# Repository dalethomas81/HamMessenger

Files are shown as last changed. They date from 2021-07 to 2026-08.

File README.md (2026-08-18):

> **⚠️ This repository is archived and no longer maintained.**  
> The code is left available for reference. No further updates, issues, or pull requests will be accepted.
> Please see [Meshtastic](https://meshtastic.org) or [Meshcore](https://meshcore.io) as superior alternatives. 

# HamMessenger # 
  
  

Hands on article about HamMessenger in IEEE Spectrum magazine [here](https://spectrum.ieee.org/ham-radio-text-hacking)  
Arduino blog post on HamMessenger [here](https://blog.arduino.cc/2021/07/27/send-text-messages-over-ham-radio-with-the-hammessenger/?queryID=undefined)  
Hackaday blog post on HamMessenger [here](https://hackaday.com/blog/?s=hammessenger)  

HamMessenger is a portable, battery powered device that runs on a microcontroller and interfaces with an inexpensive ham radio to send and receive text messages and provide position updates using the [APRS](http://www.aprs.org/doc/APRS101.PDF) protocol. Messages and position updates sent via HamMessenger can be viewed on sites such as [aprs.fi](https://aprs.fi). HamMessenger messages are NOT encrypted!  

HamMessenger is intended to be used by licensed ham radio operators. For more information you can check out the [ARRL](http://www.arrl.org/what-is-ham-radio) website.  

The goal of the HamMessenger project is to create a device that uses ham radio as a medium for sending and receiving text messages. HamMessenger exists also to promote amateur radio, electronics, and programming. The project is currently in a beta prototyping stage but does function quite well. 

At the core of the the project is the [MicroAPRS](https://github.com/markqvist/MicroAPRS) modem created by [markqvist](https://github.com/markqvist). The primary controller is an Arduino Mega 2560 with the MicroAPRS Modem running on an Arduino Pro Mini. HamMessenger includes GPS functionality supplied by a Neo-6M GPS radio. For peripherals, an M5Stack CardKB keyboard is used for input and an SSD1106 Oled display for output.  

I will add some videos and pictures of the device in action asap. Please feel free to contribute to the project. I am very busy outside of this project so any help is greatly appreciated :)  

<table>
  <tr>
    <td align="center">
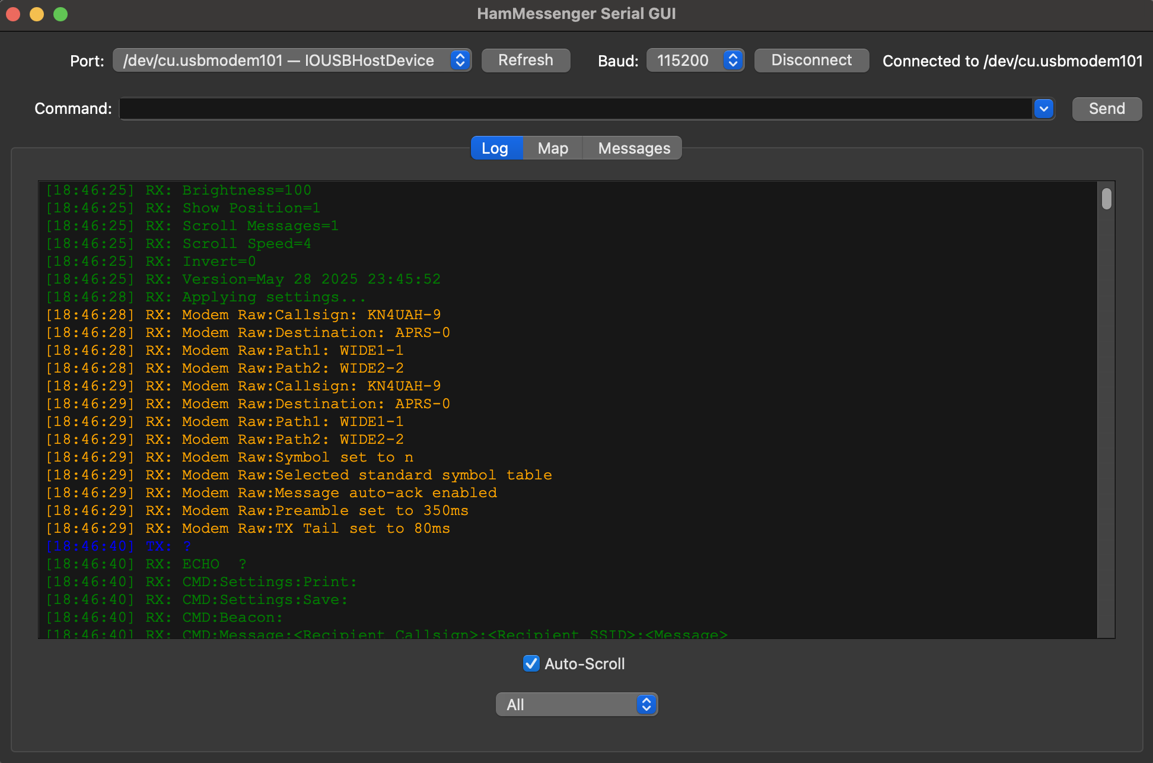
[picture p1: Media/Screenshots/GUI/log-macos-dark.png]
      <br/>
      <sub>MacOS Log Screen</sub>
    </td>
    <td align="center">
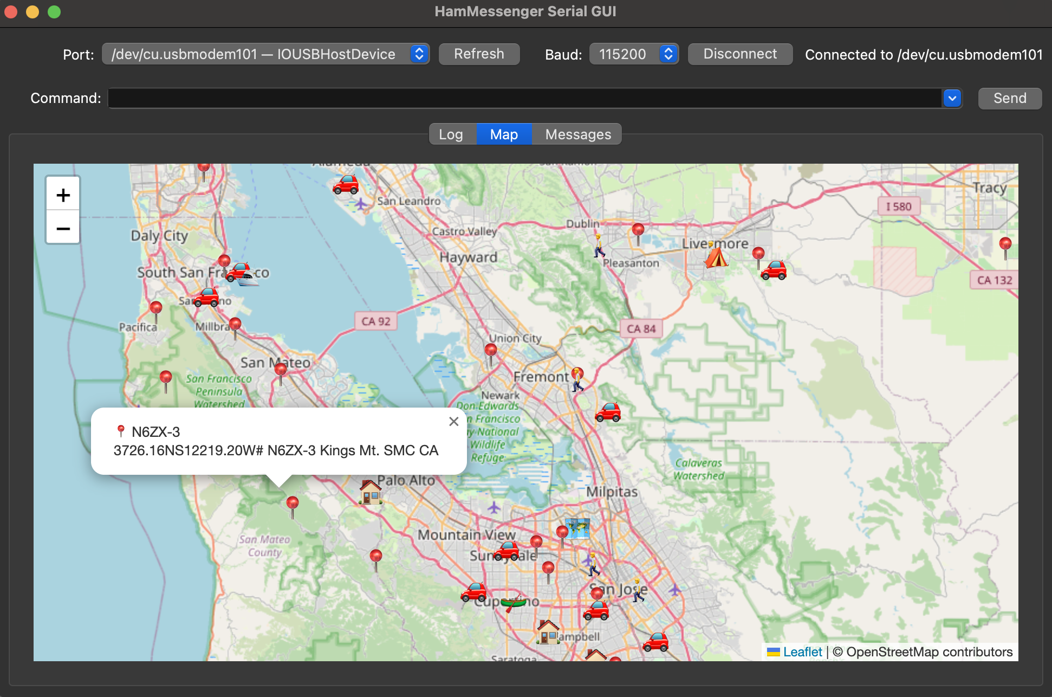
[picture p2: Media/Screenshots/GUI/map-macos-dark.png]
      <br/>
      <sub>MacOS Map Screen</sub>
    </td>
  </tr>
</table>

<table>
  <tr>
    <td align="center">
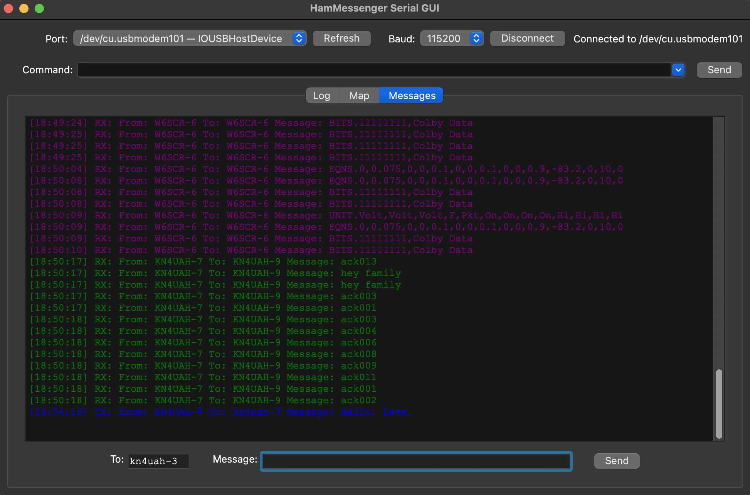
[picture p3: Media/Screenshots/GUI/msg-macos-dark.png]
      <br/>
      <sub>MacOS Message Screen</sub>
    </td>
    <td align="center">
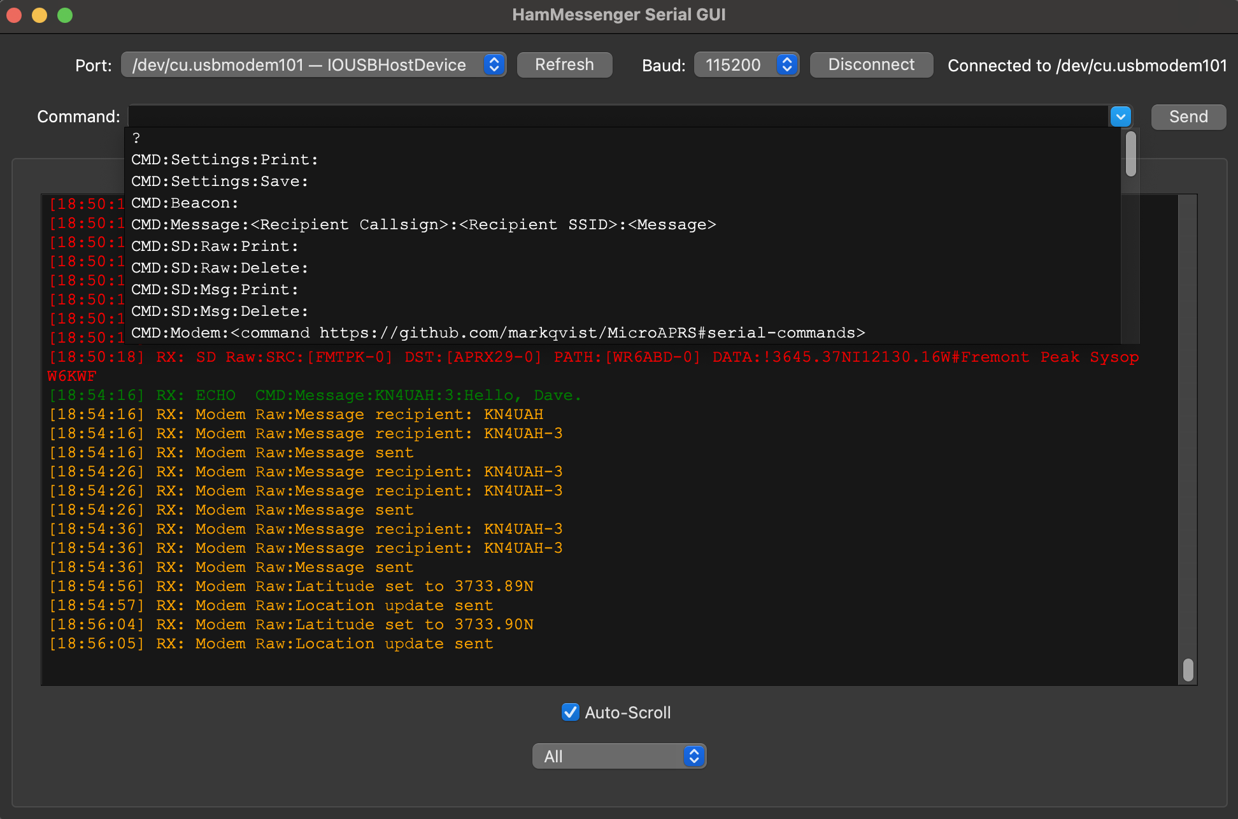
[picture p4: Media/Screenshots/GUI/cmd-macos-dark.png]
      <br/>
      <sub>MacOS Commands Example</sub>
    </td>
  </tr>
</table>

<table>
  <tr>
    <td align="center">
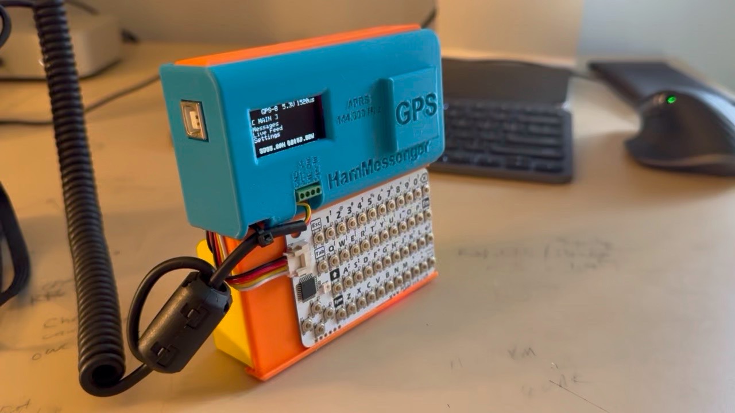
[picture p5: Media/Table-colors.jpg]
      <br/>
      <sub>Full Enclosure</sub>
    </td>
    <td align="center">
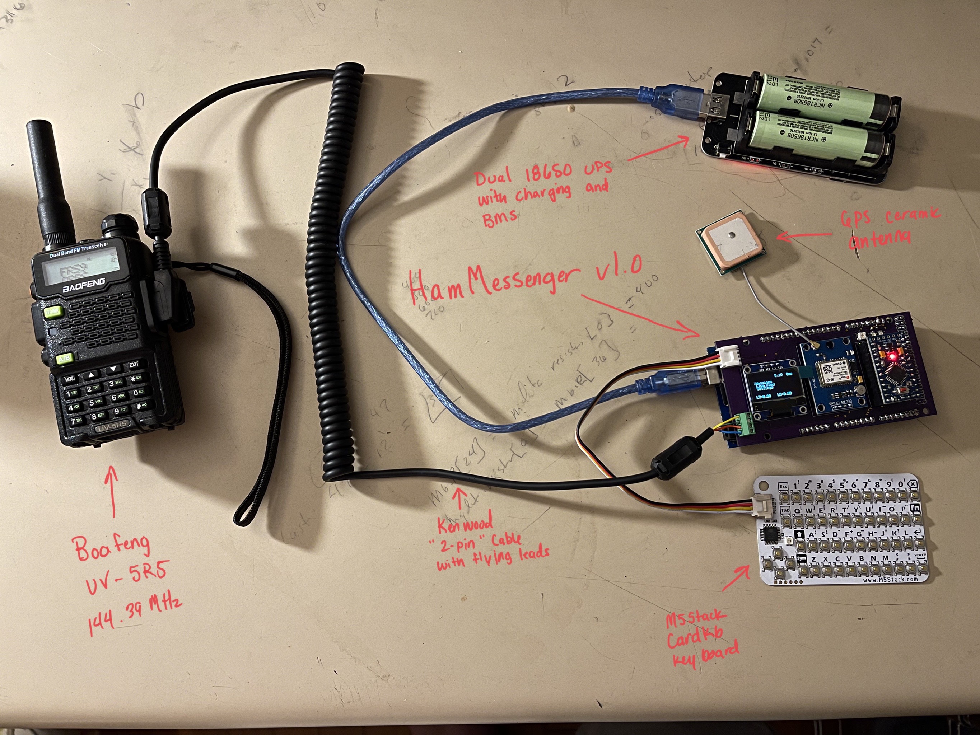
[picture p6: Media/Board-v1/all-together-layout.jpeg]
      <br/>
      <sub>Component Layout</sub>
    </td>
    <td align="center">
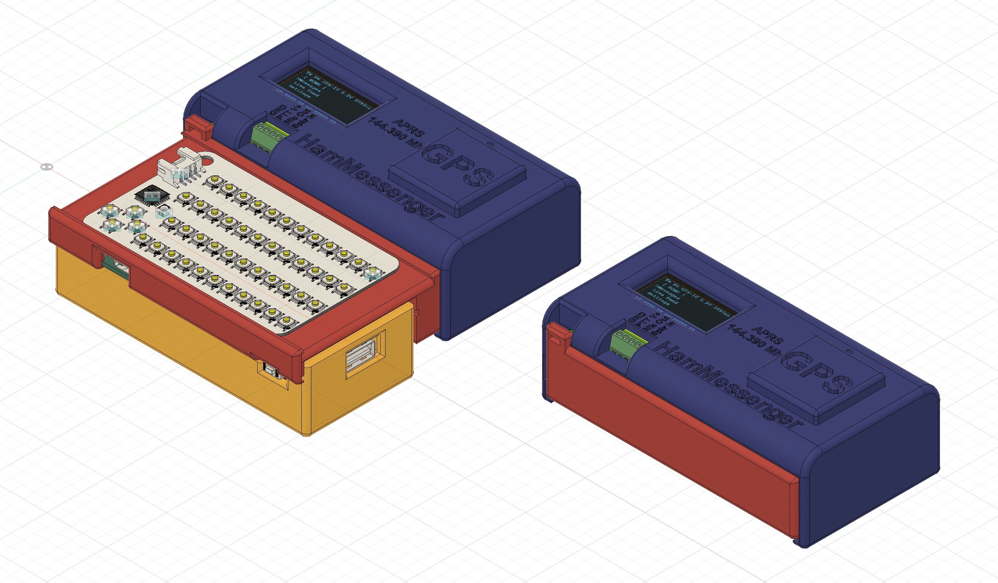
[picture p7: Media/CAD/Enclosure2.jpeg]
      <br/>
      <sub>CAD Isometric</sub>
    </td>
  </tr>
</table>

## Operation ##

Full instructions on how to operate HamMessenger will go here. For now, just a couple notes :)  

HamMessenger will beacon your location and comment according to the 'Beacon' settings in `APRS` Settings.  
- `Beacon Distance` is the distance in miles that will trigger a beacon.  
- `Beacon Idle Time` is the time in milliseconds that the station must be in the same location after having moved from the last beacon location before a beacon will be sent.
- `Position Tolerance` under `GPS` settings is the +/- value that will trigger a location update.  

To send a direct message to a station, select `Messages` on the `HOME` screen and press `Enter` on the keyboard. This will open the `NEW MESSAGE` screen.  
- `Message Text` is the message that will be sent.  
- `Recipient Callsign` is the callsign of the station that will recieve the message. Example 'NOCALL-ID'  
- `Recipient SSID` is the ID of the station that will recieve the message. Example 'NOCALL-ID'  

Screen navigation information can be found [here](https://github.com/dalethomas81/HamMessenger/blob/master/Documentation/Operating%20Instructions/Screen%20Navigation.md).  

Radio setup instructions can be found [here](https://github.com/dalethomas81/HamMessenger/blob/master/Documentation/Operating%20Instructions/Radio%20Setup.md).

Serial interface information can be found [here](https://github.com/dalethomas81/HamMessenger/blob/master/Documentation/Operating%20Instructions/Serial%20Interface.md).

## TODO ##

hardware:
- improve enclosure design  

software:
- add ability to program the radio once connected for 'plug-n-play' experience (is this possible?)  
- add feature to be selective about message acknowledgments. currently any acknowlegment (from a second conversation) will reset the messaging sequencer.  

## Libraries ##

Here are links to the non-standard libraries that I am using for this project. All other libraries are standard and can be installed using the library manager built into the Arduino IDE.  
- https://github.com/wonho-maker/Adafruit_SH1106  
- https://github.com/mikalhart/TinyGPSPlus  
- https://github.com/adafruit/Adafruit-GFX-Library  
- https://github.com/Xander-Electronics/Base64  

## Compilation ##

The easiest way to compile HamMessenger is to use the Ardunio IDE. After all libraries are installed you can use the Verify button to compile or the Upload button to compile and write the binary to the main controller M1. 

The Arduino source code for HamMessenger can be found [here](/Source/HamMessenger).

The modem controller does not need to be compiled as the binary files are already made available [here](https://github.com/markqvist/MicroAPRS/tree/master/precompiled).  

You can use AVRDude to write the binary to the modem controller. Instructions on how to do that will be coming soon. In the meantime, if you already know how to install and use AVRDude then feel free to make use of the [batch](/Source/MicroAPRS%20Firmware%20Installer) file I created and an [FTDI](https://www.amazon.com/gp/product/B00DDF8TV6/ref=ox_sc_act_title_4?smid=A2SXV8GJXX3WPH&psc=1) serial cable to write to the modem.

## Parts ##

Find BOM information on parts [here](/Documentation/Parts/BOMs)  
Find Drawing information on parts [here](/Documentation/Parts/Drawings)  
Find Vendor information on parts [here](/Documentation/Parts/Vendors)  

### Part Specs ###

Arduino:  
https://gallery.autodesk.com/fusion360/projects/arduino-mega-2560-r3  

Keyboard:  
https://github.com/m5stack/M5-ProductExampleCodes/tree/master/Unit/CARDKB  

OLED Display:    
https://grabcad.com/library/0-96-oled-display-4-pin-1  
https://grabcad.com/library/ecran-oled-1-3-1

Modem:  
https://github.com/markqvist/MicroAPRS  
https://github.com/markqvist/MicroAPRS/blob/master/precompiled/microaprs-5v-ss-latest.hex  
https://github.com/markqvist/MicroAPRS/blob/master/documentation/Hardware%20Schematic.pdf  
https://unsigned.io/shop  
https://unsigned.io/product/micromodem-r23b  

GPS:    
https://grabcad.com/library/gps-module-ublox_neo6mv2-1  
https://grabcad.com/library/ecran-oled-1-3-1  

Grove Connector:  
https://grabcad.com/library/grove-connectors-stand-and-flat-male-plugs-1/details?folder_id=2820551  

Battery:  
Panasonic 18650 - don't have a link but you can get them on eBay or Amazon  

## Updates ##

### 31-MAY-2025: Major updates!

I have made some major updates to the board (RF filtering for the PTT), to the enclosure, and to the firmware (many improvements to the display including a dedicated "New Message" display). Additionally, I have created a companion GUI app that you can use to connect HamMessenger to your PC.  

I have ordered parts to begin building 3 new HamMessengers and will begin building them next week. The purpose is to create some instructional videos and documentation to help support anyone that wants to build one themselves. I also plan to donate these builds to my local Ham club.  

There is now a new [Build Instructions](/Documentation/Build%20Instructions/) folder that I will use to put the tutorial references and documentation.  

### 08-SEP-2021: Troubleshooting freezing

There is an issue where during transmit the unit will freeze or restart. I did some experimenting and found out that its the cable that connects to the radio. It is not shielded at all. I thought the small ferrites would be enough to combat this but obviously not. I did some experimenting and found that if I use larger ferrites and wrap them once that the issue goes away. [Here](/Media/Install/large-ferrites.jpeg/) is a picture of the installation. I will now look at sourcing a shielded cable for this application.

### 05-SEP-2021: First version of the enclosure

So I started learning 3D modeling so that I can create an enclosure for HamMessenger. Its been a bit of a learning curve but I'm getting the hang of it. I decided that for the first iteration I would go with an open unibody frame. I chose this style for the first version because it is easy and I'd like to have something working while I learn more about 3D modeling.

You can find the Fusion 360 archive file and the stl [here](/Documentation/CAD/Fusion-360/). It needs to be printed on its side like [this](/Media/Unibody-Frame-v1/cura.png/) to minimize the amount of support needed during printing. I used 0.2mm layers with 20% infill as well as 5% support infill. The print took about 6.5 hours.

A few pics:  
[Front](/Media/Unibody-Frame-v1/front.jpeg/)  
[Side](/Media/Unibody-Frame-v1/side.jpeg/)  
[Back](/Media/Unibody-Frame-v1/back.jpeg/)  

### 14-AUG-2021: Rev v1.1 has arrived and it works!

Ok, great news. Revision v1.1 of the HamMessenger board came in from PCBWay and they are great. I built 2 units and was able to encode and decode messages well. I will add some more information later but [here](/Media/Board-v1.1/) is a few pictures for now.

### 24-JUL-2021: Rev v1.1 is being fabbed!!

I was able to work through all of the issues with the first version. I placed an order with jlcpcb this time (osh park was great but too expensive). I ordered 20 boards this time and if they work well I will give some away.  

I'll update later with how I resolved the issues. For now, going to have a beer :)

### 22-JUL-2021: Put together some information on the board for your review.

[Here](/Media/Board-v1/analysis.md) is an in-depth analysis of the problems with version 1.0 of the board. Also, does any body know how to add correct shielding for the board? I am having issues with the Arduino locking up on transmit sometimes.

### 21-JUL-2021: Made revisons to the board resolving and improving the following:

1. add ground to SD card
2. add OE connection to line leveler
3. reverse I2C connections
4. change GPS I/O to correct serial
5. purchase correct GPS (added new link in BOM)
6. move SD card away from USB.
7. move keyboard grove to bottom of board and out of way
8. move 4 pin terminal for cable such that it is out of the way of larger OLED
9. ground plane improvements.  

still left to do:

1. board does not receive (soldering issues?)  
2. board some times locks up during transmit (ground plane issues?)  

### 20-JUL-2021: Bad news on the boards :( Lots of problems. I will begin immediately working on a revision. Here is a list of the issues:

1. SD Card missing ground
2. Line leveler missing OE connection.
3. I2C connections are reversed.
4. GPS is pointing to wrong serial ports (can fix with code but might as well make it right).
5. GPS pins do not match board. (worked around this by shifting pins)
6. Cannot not receive (don't know why at this point).
7. SD card hits Arduino USB. Will move it and the Grove connector to make room.
8. Arduino periodically locks up. Seemingly due to RF? Had this issue with prototype board but fixed it with ferrites.

### 18-JUL-2021: The printed circuit boards from OSH will be arriving tomorrow! I have added all of the parts needed to build HamMessenger [here](/Documentation/Parts/BOMs).

04-JUL-2021: Version 1 of the pcb for HamMessenger has be sent for fabrication. The estimated delivery date is the 22nd of July. In the meantime I will be ordering the components to populate the board. As I do that I will make sure to get the links for the components and add them to the BOM in the Eagle folder.

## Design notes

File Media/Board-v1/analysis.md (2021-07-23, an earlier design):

# Analysis of HamMessenger v1.0 #  

After receiving the board and soldering the SMD components, it became very apparent that a new revision would be in order. Here is what I found...  

# Form #

1. At first sight you can see that the board will not mate flush with the Arduino due to poor placement of the SD card mechanism and the Grove connector. I will be moving these as one of the first improvements.
2. Next, you can see that the modem (Arduino Pro Mini) has all of its supporting hardware mounted underneath it. This was done on purpose to save space but I think a better option would have been to place the components on the other side of the board. I may do that in a later revision. But, for now I have added female 2.54mm headers so that the Pro Mini can be removed for troubleshooting and repair.
3. The last major form issue is the display. It is just too small. The prototype version uses a non-standard 1.2" OLED that is controlled by a sh1106 instead of a ssd1306 (and consequently needs a modified library). I decided that I would give the standard 0.96" display a try since they are very common and use the out-of-the-box version of the Adafruit ssd1306 library. However, its just too damn small!
4. Bonus: while we're on the subject of form - you will notice how terrible of a job I did on the smd soldering. It was my first time but I think (hope) the next board will look better :)

# Function #

1. The first functional issue was with the SD card. This actually counts as 2 issues. One was that I missed a ground on my SD card mechanism. The other was that I missed feeding vcc to the OE pin of the line-level shifter. I repaired both of those with jumpers so that I could troubleshoot the rest of the board.
2. The next functional issue is that the OLED display and the keyboard would not work. I had gotten the SDA and SCL lines for I2C crossed. You'll see a picture below of the disgusting job I did of fixing that.
3. Next, you can see that I ordered the wrong GPS unit (correct one on the BOM now). Luckily, it worked out that the correct one has an extra pin (pps) and it just so happened that I could scoot this one over a pin and run a jumper for the power and get it to work. So technically, this isn't an issue with the board but I'm listing it here.
4. After I got the GPS installed and powered, I noticed that the coordinates were not being populated in the bottom of the display. This was because I routed the serial wires to the wrong serial ports of the Arduino. Doh. That was an easy change in the software to get this one working but I will make it right on the next version of the board.
5. Moving on to encoding and decoding messages - it doesn't encode messages as good as the prototypes and I haven't gotten it to *decode* a message at all yet. I'm going to remove the Arduino Pro Mini and try to reflow some of those components. Admittedly, I did not do a very good job soldering these.
6. Oh, and lastly - sometimes the Arduino will lock up on transmit. This was an issue that I saw with the prototype boards and thought it must be an issue with not having a ground plane or shielding. I "fixed" the issue by adding ferrite cores to the cable between HamMessenger and the radio. The problem went away but it is now present in this board even with the ferrite cores. If anyone knows a thing or 2 about how to shield this board from RF, I would love to hear from you.

# Pictures #

all-together-layout  

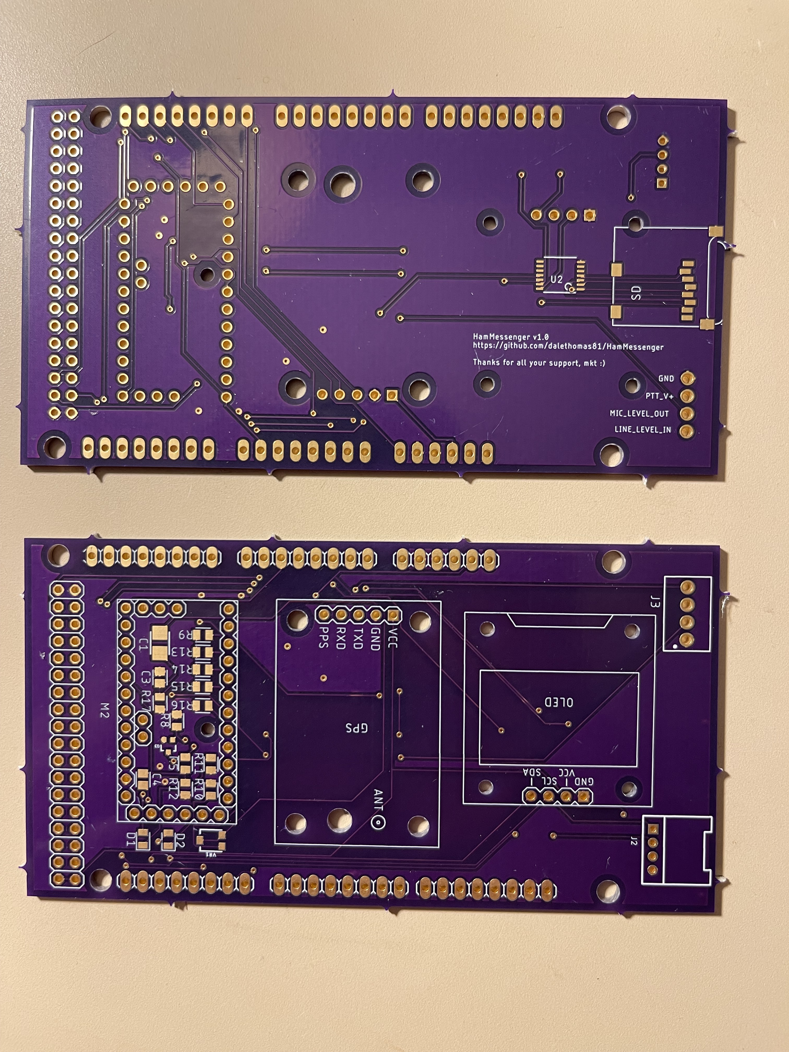
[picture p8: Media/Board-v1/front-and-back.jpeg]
front-and-back
  

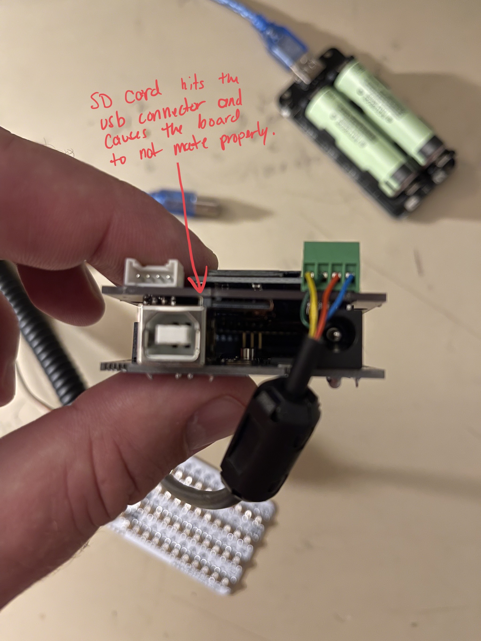
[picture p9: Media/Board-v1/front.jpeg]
front
  

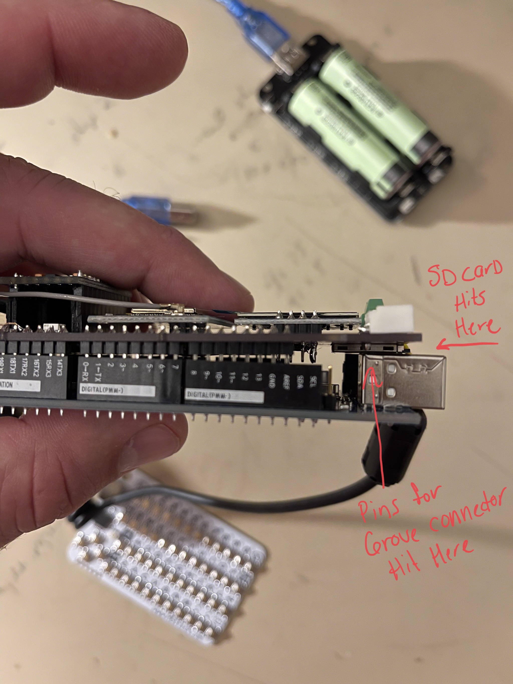
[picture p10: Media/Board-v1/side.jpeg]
side
  

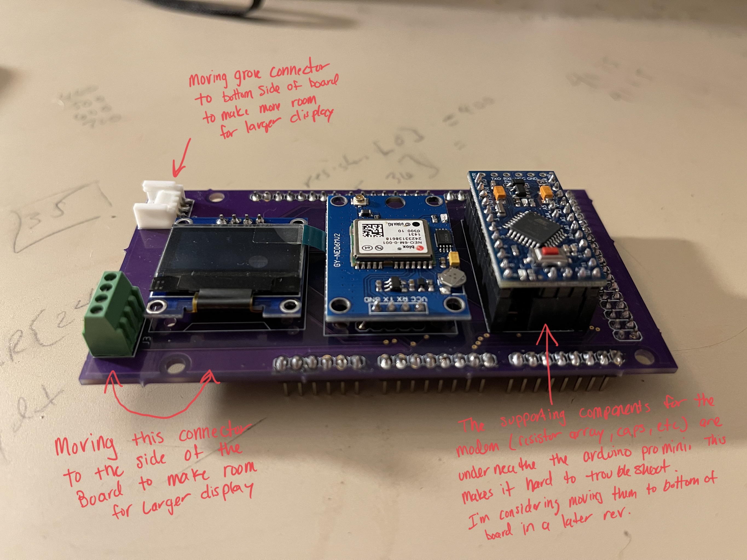
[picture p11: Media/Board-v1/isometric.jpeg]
isometric
  

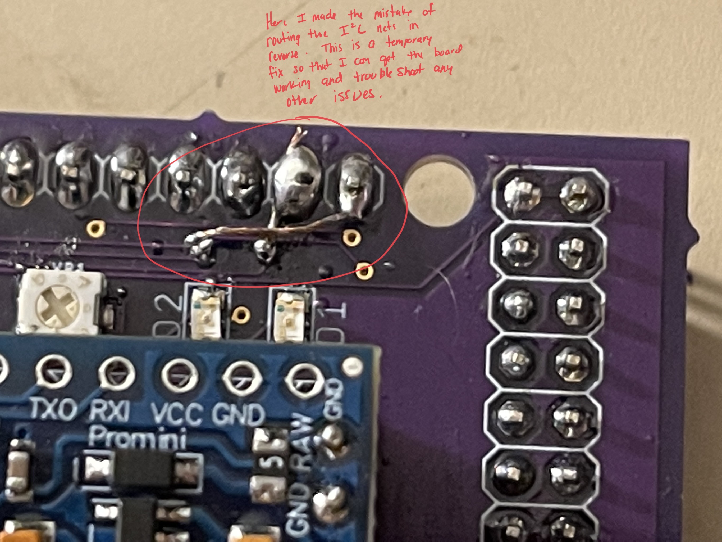
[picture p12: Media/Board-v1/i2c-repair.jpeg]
i2c-repair
  

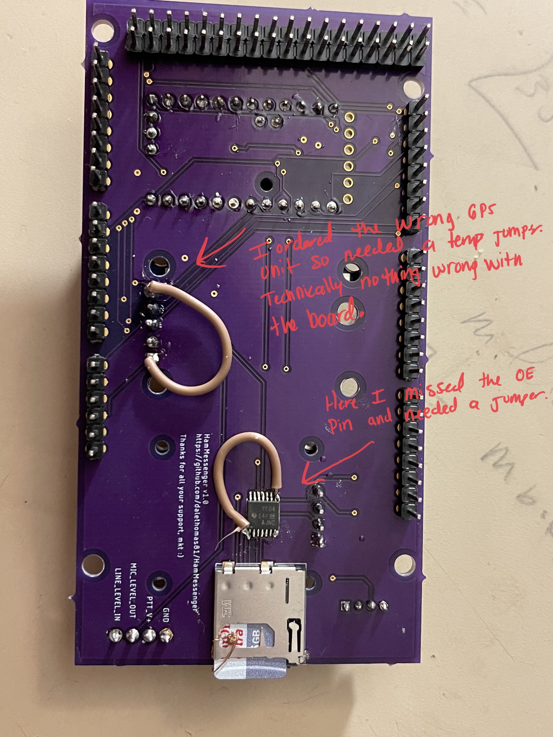
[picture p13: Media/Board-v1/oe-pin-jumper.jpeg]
oe-pin-jumper
  

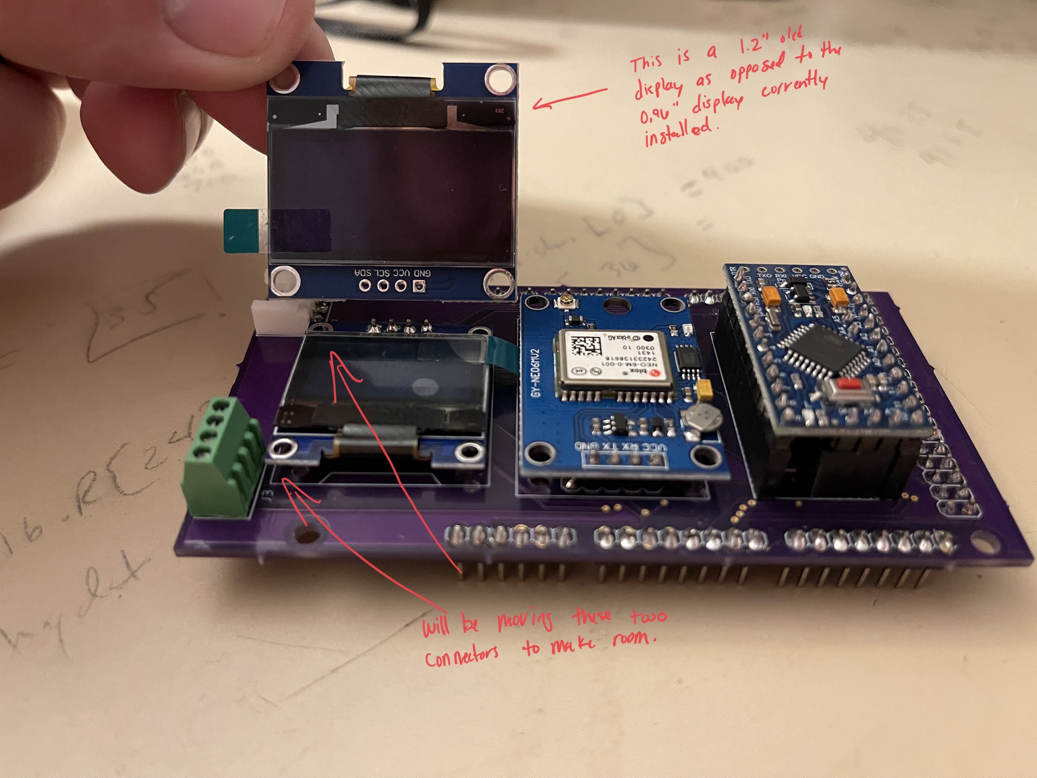
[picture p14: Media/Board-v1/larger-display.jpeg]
larger-display


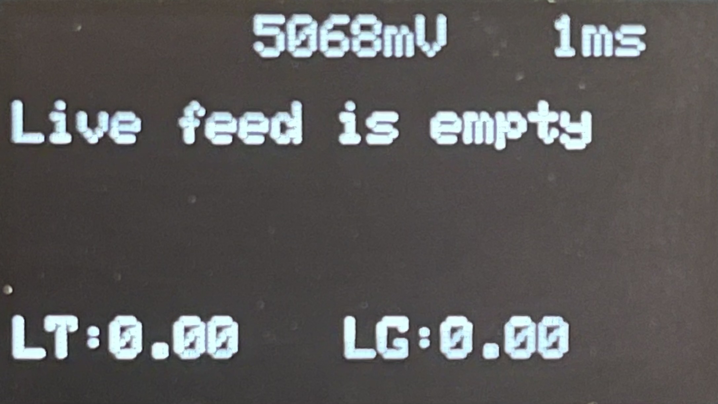
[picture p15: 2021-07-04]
Media/Screenshots/LiveFeed_Empty.jpeg

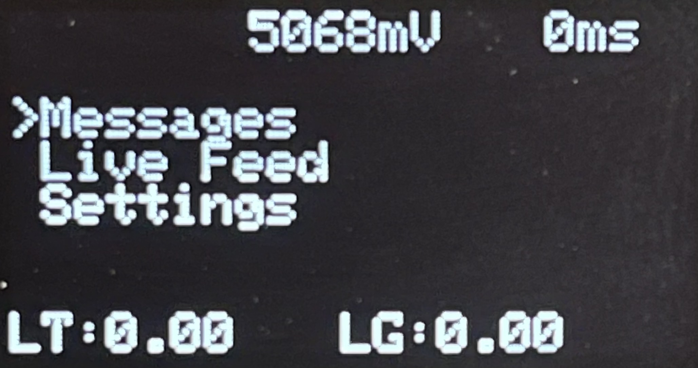
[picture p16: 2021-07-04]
Media/Screenshots/Home.jpeg

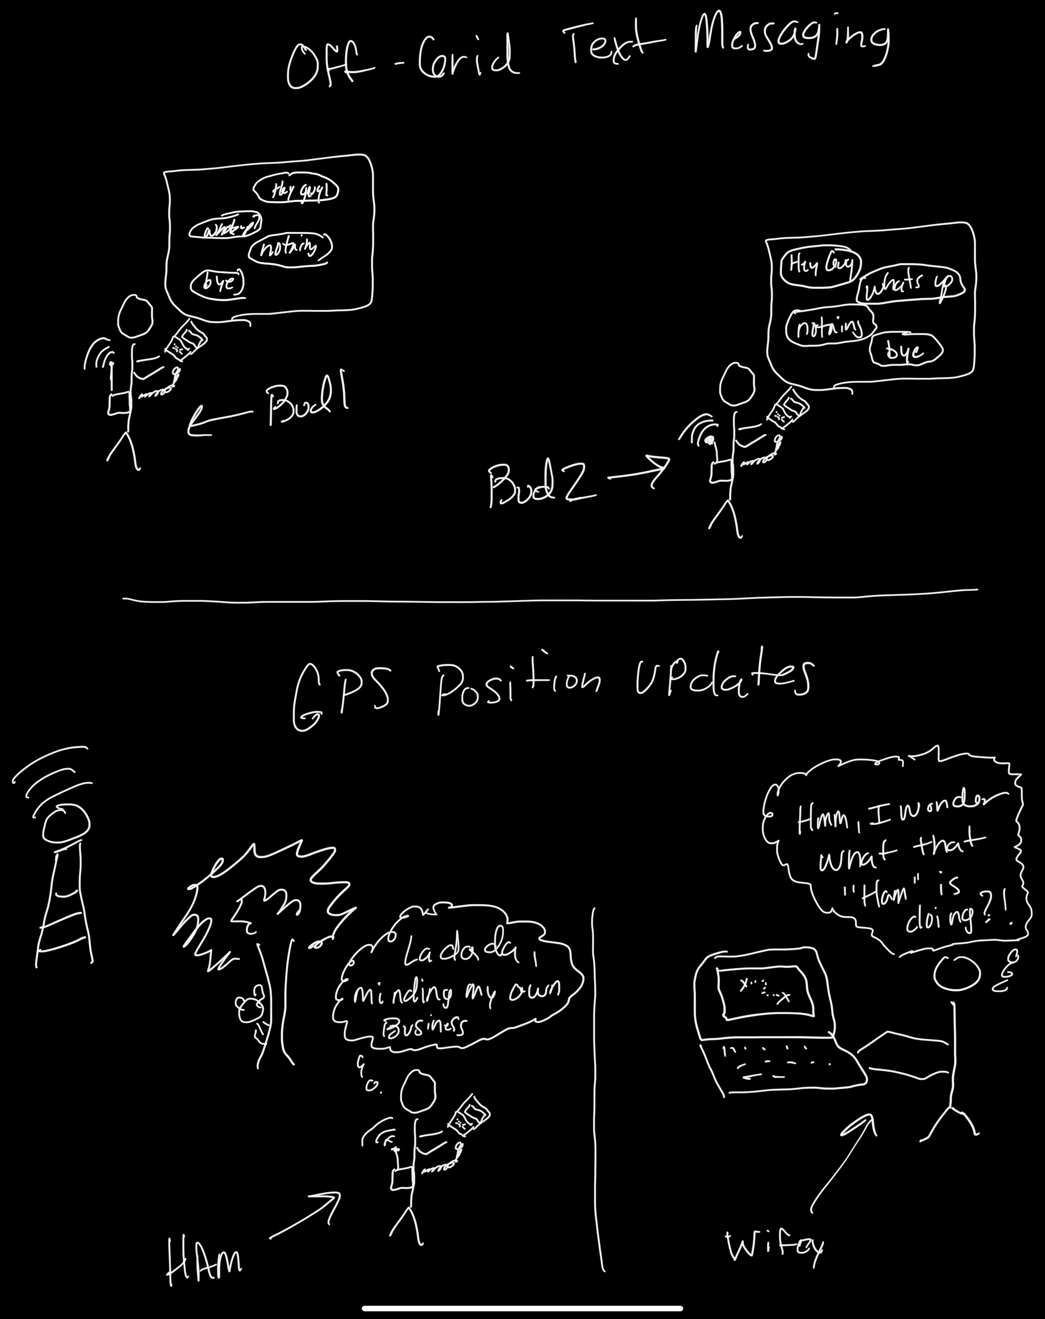
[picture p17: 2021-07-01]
Media/Illustration-Dark.jpeg

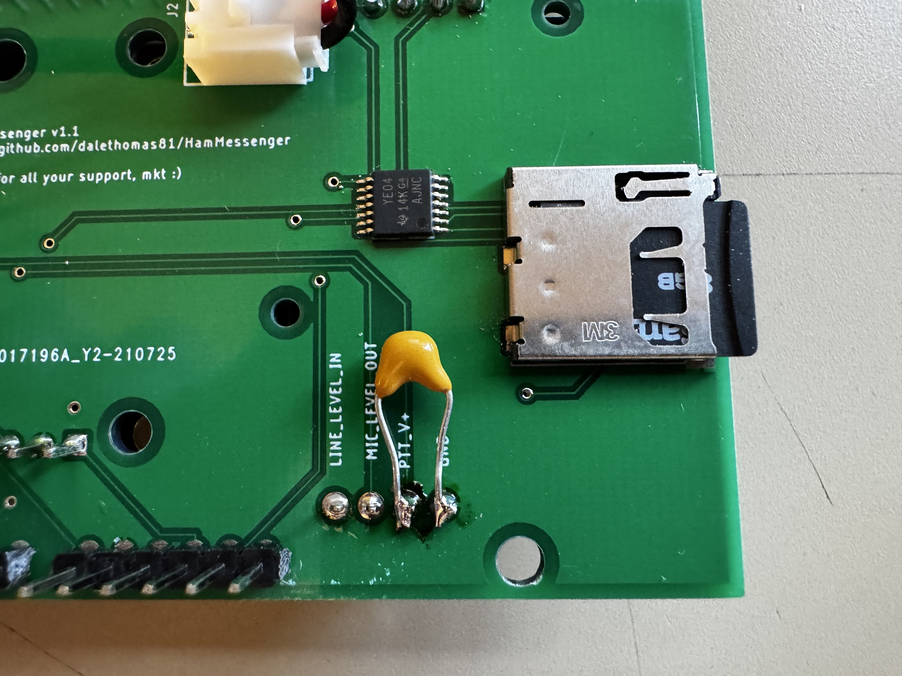
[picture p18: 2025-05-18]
Media/Board-v1.1/RF-Cap.jpeg

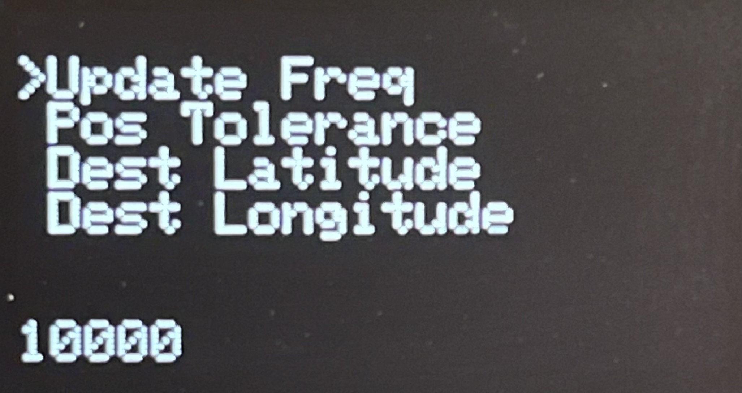
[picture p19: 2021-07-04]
Media/Screenshots/Settings_GPS.jpeg

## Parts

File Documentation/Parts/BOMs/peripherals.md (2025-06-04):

| Part | Qty | Manufacturer | Manufacturer # | Description | Link |
| ---- | --- | --- | --- | --- | ---- |
| KEYBOARD | 1 | M5Stack | CardKB | Card Keyboard I2C | https://www.mouser.com/ProductDetail/M5Stack/U035-B?qs=vvQtp7zwQdP58CzuvFQT0A%3D%3D
| CABLE | 1 | Various | Kenwood 2-pin | Kenwood 2-pin connector | https://www.amazon.com/dp/B08HT277B4?psc=1&smid=AZRLOQSTLHOAO&ref_=chk_typ_imgToDp 
| UPS | 1 | Various | unknown | UPS battery power supply | https://www.amazon.com/gp/product/B07SZKNST4/ref=ppx_yo_dt_b_asin_title_o06_s00?ie=UTF8&psc=1
| PINS | 60+ | Various | Unknown | 2.54mm header pins | https://www.amazon.com/gp/product/B06XR8CV8P/ref=ppx_yo_dt_b_asin_title_o01_s00?ie=UTF8&psc=1
| RADIO | 1 | Baofeng | UV-5R5 | https://www.amazon.com/gp/product/B091YLJ6CN/ref=ppx_yo_dt_b_asin_title_o00_s02?ie=UTF8&psc=1
| FERRITE | 1 | various | Unknown | Ferrite rings for cables | https://www.amazon.com/gp/product/B01E5E5IY4/ref=ppx_yo_dt_b_asin_title_o07_s00?ie=UTF8&psc=1
| PCB | 1 | Various | HamMessenger v1.2 | Printed circuit board for HamMessenger | Use Gerber files in Source/CAD/Fusion-360/Builds on a site like PCBWay.com
| battery | 2 | Various | 18650 battery | https://www.mouser.com/ProductDetail/SparkFun/PRT-12895?qs=WyAARYrbSnY5bEhbpFpipQ%3D%3D
| SD Card | 1 | Various | SD Card 8gb | https://www.mouser.com/ProductDetail/SanDisk/SDSDQAB-008G?qs=EgF7oUuTQmoYk8ahPy9gPg%3D%3D

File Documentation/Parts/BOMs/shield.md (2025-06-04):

| Part | Qty | Manufacturer | Manufacturer # | Description | Link |
| ---- | --- | --- | --- | --- | ---- |
| D2 | 1 | BIVAR | SM0805URC | Standard LEDs - SMD Ultra Red 660 nm Water Clear | https://www.mouser.com/ProductDetail/749-SM0805URC
| D1 | 1 | BIVAR | SM0805UGC | Standard LEDs - SMD Ultra Green 525 nm Water Clear | https://www.mouser.com/ProductDetail/749-SM0805UGC
| C4 | 1 | KEMET | C0805C105J4RECTU | Multilayer Ceramic Capacitors MLCC - SMD/SMT 16V 1uF X7R 0805 5% | https://www.mouser.com/ProductDetail/80-C0805C105J4RECTU
| C2,C3 | 2 | KEMET | C0805C104J4RACTU | Multilayer Ceramic Capacitors MLCC - SMD/SMT 16V 0.1uF X7R 0805 5% | https://www.mouser.com/ProductDetail/80-C0805C104J4R
| C1 | 1 | KEMET | T591B475M035ATE200 | Tantalum Capacitors - Polymer 35V 4.7uF 1311 20% E SR=200mOhm AEC-Q200 | https://www.mouser.com/ProductDetail/80-T591B475M35ATE200
| R1 | 1 | Bourns | CR0805-JW-101ELF | Thick Film Resistors - SMD 100ohm 5% | https://www.mouser.com/ProductDetail/Bourns/CR0805-JW-101ELF?qs=wL7NMIHXUPl5EcPQbx1sug%3D%3D
| J2 | 1 | Seeed Studio | 110990037 | Seeed Studio Accessories Grove - Universal 4 pin connector 90 (10 PCs) | https://www.mouser.com/ProductDetail/713-110990037
| J3 | 1 | TE Connectivity | 282834-4 | Fixed Terminal Blocks 4P SIDE ENTRY 2.54mm | https://www.mouser.com/ProductDetail/571-282834-4
| Q3 | 1 | Nexperia | 2N7002PW,115 | MOSFET 60V 0.3A N-CHANNEL TRENCH MOSFET | https://www.mouser.com/ProductDetail/771-2N7002PW-115
| R8 | 1 | ROHM Semiconductor | SFR10EZPJ103 | Thick Film Resistors - SMD 10Kohm 0805 5% | https://www.mouser.com/ProductDetail/755-SFR10EZPJ103
| R5,R12 | 2 | ROHM Semiconductor | SFR10EZPJ104 | Thick Film Resistors - SMD 100Kohm 0805 5% | https://www.mouser.com/ProductDetail/755-SFR10EZPJ104
| R15 | 1 | ROHM Semiconductor | KTR10EZPJ822 | Thick Film Resistors - SMD 0805 8.2Kohm 5% High Voltage | https://www.mouser.com/ProductDetail/755-KTR10EZPJ822
| R14 | 1 | ROHM Semiconductor | KTR10EZPJ392 | Thick Film Resistors - SMD 0805 3.9Kohm 5% High Voltage | https://www.mouser.com/ProductDetail/755-KTR10EZPJ392
| R13 | 1 | ROHM Semiconductor | KTR10EZPJ222 | Thick Film Resistors - SMD 0805 2.2Kohm 5% High Voltage | https://www.mouser.com/ProductDetail/755-KTR10EZPJ222
| R9,R16,R11 | 3 | ROHM Semiconductor | KTR10EZPJ102 | Thick Film Resistors - SMD 0805 1Kohm 5% High VoltageAEC-Q200 | https://www.mouser.com/ProductDetail/755-KTR10EZPJ102
| R17 | 1 | Panasonic | ERJ-6GEYJ271V | Thick Film Resistors - SMD 0805 270ohms 5% AEC-Q200 | https://www.mouser.com/ProductDetail/667-ERJ-6GEYJ271V
| R10 | 1 | Panasonic | ERJ-6GEYJ274V | Thick Film Resistors - SMD 0805 270Kohms 5% AEC-Q200 | https://www.mouser.com/ProductDetail/667-ERJ-6GEYJ274V
| SD | 1 | 3M | 2908-05WB-MG | Memory Card Connectors MICROSD 8P P/P SMT POLARIZED | https://www.mouser.com/ProductDetail/517-2908-05WB-MG
| U2 | 1 | Texas Instruments | TXB0104PWR | Translation - Voltage Levels 4-Bit Bi-directional V-Level Translator | https://www.mouser.com/ProductDetail/595-TXB0104PWR
| VR1 | 1 | Bourns | 3313J-2-104E | Trimmer Resistors - SMD 3MM TRIM POT 100K SM D SEALED | https://www.mouser.com/ProductDetail/652-3313J-2-104E
| GPS | 1 | Various | gyneo6mv2 | GPS Reciever | https://a.co/d/f8HjOKv (Note: please pay attention to the pinout and form-factor. it may be necessary to solder a small jumper to match the pinout.)
| OLED | 1 | Adafruit | ssh1106 | Oled Display 128x64 I2C sh1106 1.3" | https://a.co/d/fJx9IbG (Note: you can buy many different brands jsut be sure it is a 128x64 and 1.3" ssh1106 I2C. Alternatively, you can update the firmware to match your model.)
| M1 | 1 | Arduino | Ardunio Mega 2560 R3 | Arduino Mega 2560 Dev Board | https://www.amazon.com/gp/product/B01H4ZLZLQ/ref=ppx_yo_dt_b_asin_title_o05_s01?ie=UTF8&psc=1
| M2 | 1 | Arduino | Arduino Pro Mini | Arduino Pro Mini Dev Board | https://www.amazon.com/gp/product/B07X2JGS69/ref=ppx_yo_dt_b_asin_title_o05_s01?ie=UTF8&psc=1
| Solder| 1 | Chip Quik | SMDLTB35T4 | Solder Solder Paste Sn60/Bi40 T4 35g Syringe 87% Metal Low-Temperature | https://www.mouser.com/ProductDetail/Chip-Quik/SMDLTB35T4?qs=amGC7iS6iy8V7Ynvdf414A%3D%3D

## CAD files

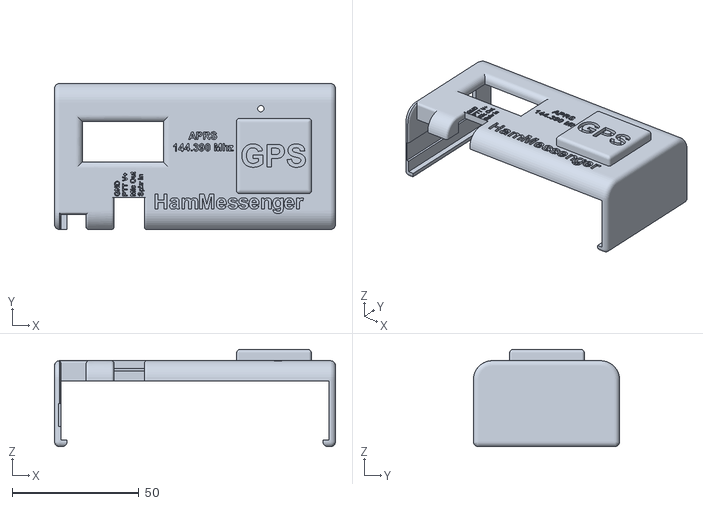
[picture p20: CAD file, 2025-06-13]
Source/CAD/Fusion-360/Builds/Front Cover.stl
111.0 x 57.8 x 38.5

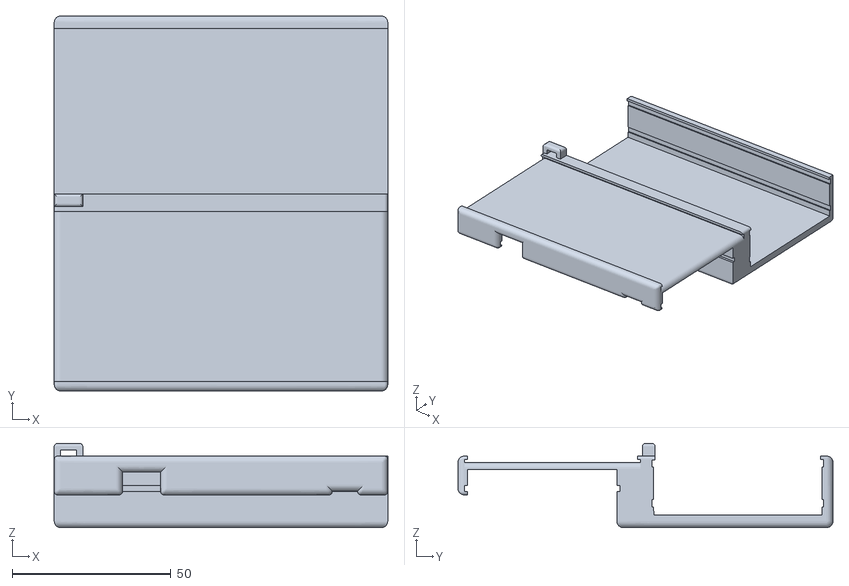
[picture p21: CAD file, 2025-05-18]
Source/CAD/Fusion-360/Builds/UniBody-Keyboard.stl
105.0 x 118.1 x 26.5

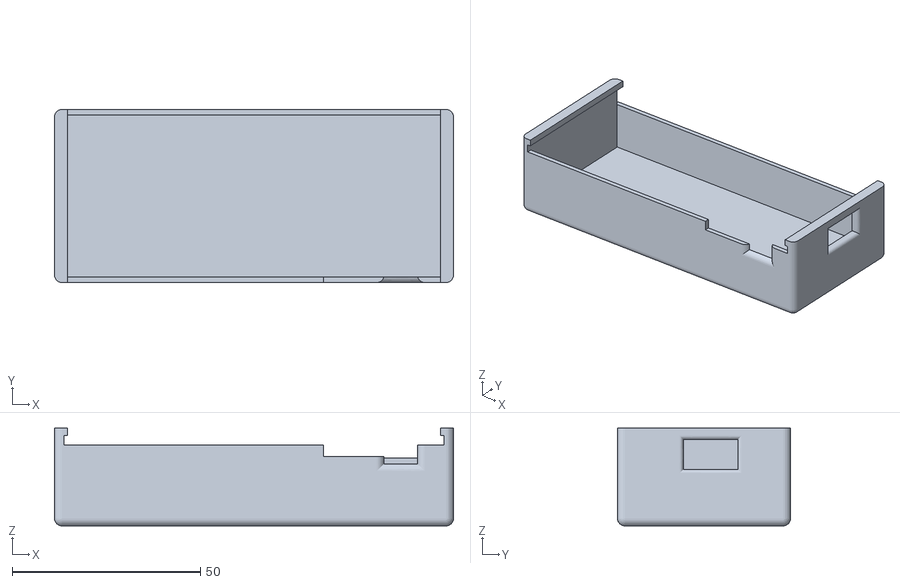
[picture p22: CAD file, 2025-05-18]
Source/CAD/Fusion-360/Builds/Back Cover.stl
106.0 x 46.0 x 26.0

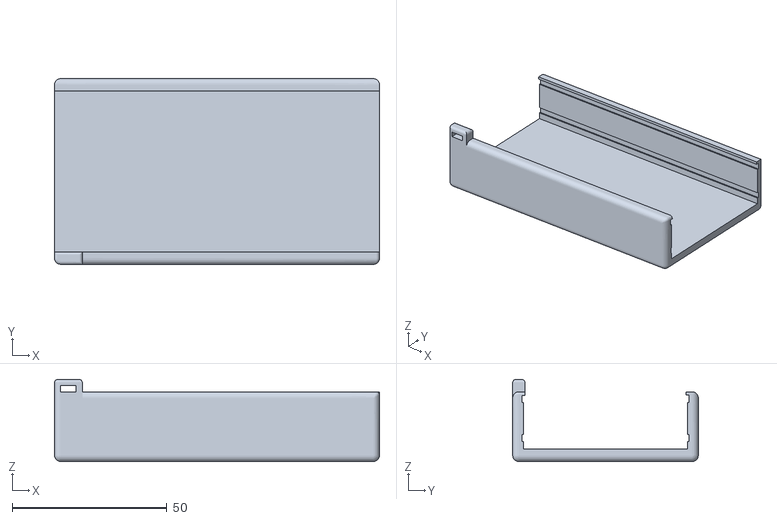
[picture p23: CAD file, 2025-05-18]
Source/CAD/Fusion-360/Builds/UniBody.stl
105.0 x 60.0 x 26.5

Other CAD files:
Documentation/Parts/Drawings/dimensioniMega.dxf
Source/CAD/Fusion-360/Enclosure.f3d

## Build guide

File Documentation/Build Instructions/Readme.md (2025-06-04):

# HamMessenger Build Instructions
I will start working on videos and tutorials and add links to them here.

## MicroAPRS Firmware Flash Instructions
See the readme [here](/Source/MicroAPRS%20Firmware%20Installer/readme.md) for complete instructions on how to flash the MicroAPRS firmware in both MacOS and Windows.

## ublox Neo 6M GPS Module
For now, there is something I want to address about the GPS module. Originally, I chose a GPS module that had a really small antenna. After using it for a while, I realize the antenna is very poor at reception. So, I decided to use a different model with a larger antenna.  

As is turns out, the model I originally used has a different pinout than most other models that have the larger and better antenna.  

However, there is a solution for the current versions of the board (currently v1.2). You can simply shift the board one pin over and solder a jumper from the vcc line to the pps through-hole (not used otherwise).  

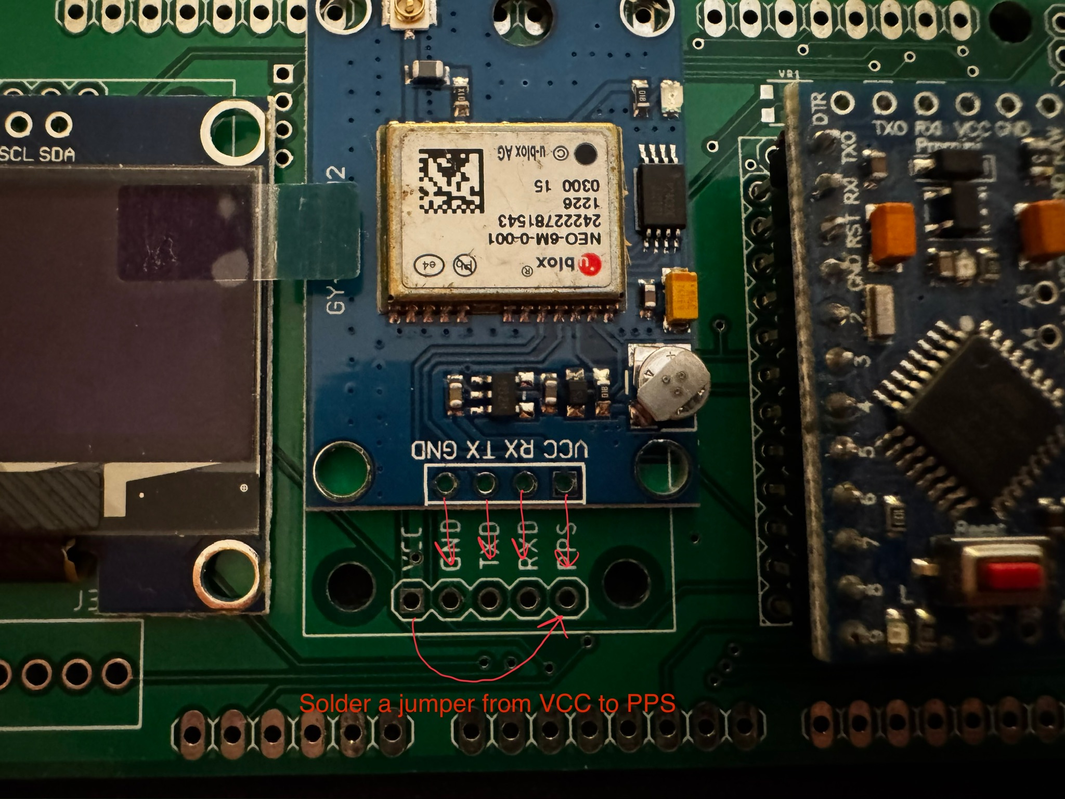
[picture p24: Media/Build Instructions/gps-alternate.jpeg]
GPS Alt


Additionally, I do plan to change this in the next board revision.

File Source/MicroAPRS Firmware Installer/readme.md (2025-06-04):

# MicroAPRS Firmware Flash Instructions
The batch and script files in this folder use AVRDUDE to flash the binarys of MicroAPRS to the Arduino Pro Mini. 
Originally I had the MicroAPRS binarys in this folder as well as a copy of AVRDUDE. 
However that is bad practice (and prob against their licenses) so I have removed them. I am leaving this batch file
here so that it can be used if needed. The [MicroAPRS](https://github.com/markqvist/MicroAPRS) repo has good information on how to flash it anyway.

## Windows
- Modify the install-windows.bat batch file to suit your configuration.  
- Using device manager set PORT manually by checking what your FTDI cable shows up as:    
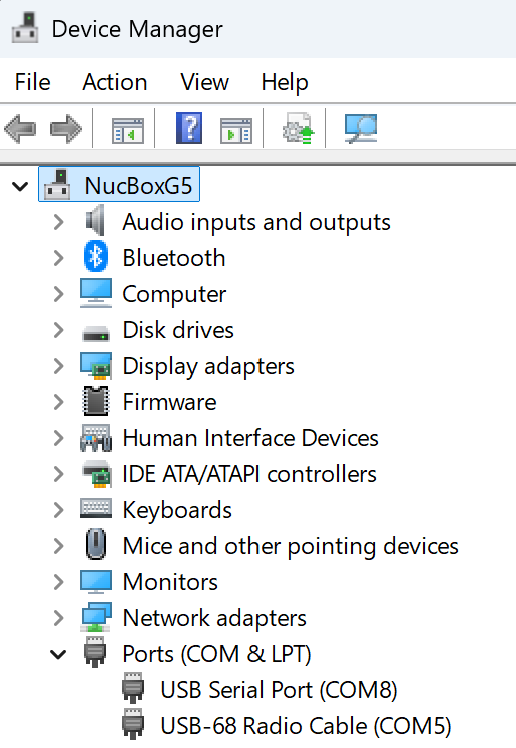
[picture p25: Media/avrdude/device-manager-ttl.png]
  
- Download the latest version of avrdude from [here](https://github.com/avrdudes/avrdude/releases) and extract it to the same folder as the install-windows.bat file.  
- Run the batch file by double-clicking on it:  
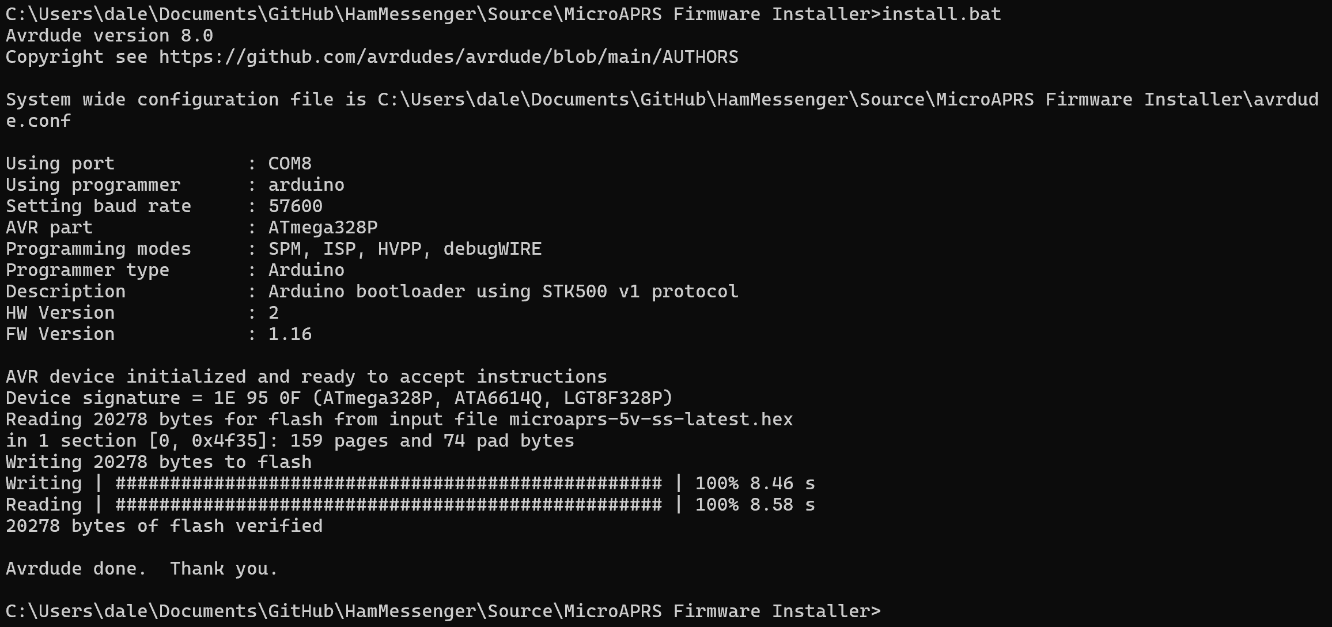
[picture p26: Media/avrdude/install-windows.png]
  

## MacOS
- Modify the install-macos.sh script to suit your configuration.  
- Using the blowe command in terminal set PORT manually by checking what your FTDI cable shows up as:  
`ls /dev/tty.*`
- Make the script executable:  
`chmod +x install-macos.sh`
- install avrdude using brew:  
`brew install avrdude`
- if brew is not installed, you can install it from terminal like this:  
`/bin/bash -c "$(curl -fsSL https://raw.githubusercontent.com/Homebrew/install/HEAD/install.sh)"`
- download the MicroAPRS precompiled binary file from [here](https://github.com/markqvist/MicroAPRS/tree/master/precompiled) and place it in the same folder as the install-macos.sh script.  
    - `microaprs-5v-ss-latest.hex` for the 5v Pro-Mini
    - `microaprs-3v-ss-latest.hex` for the 3.3v Pro-Mini
- Run the script from terminal:  
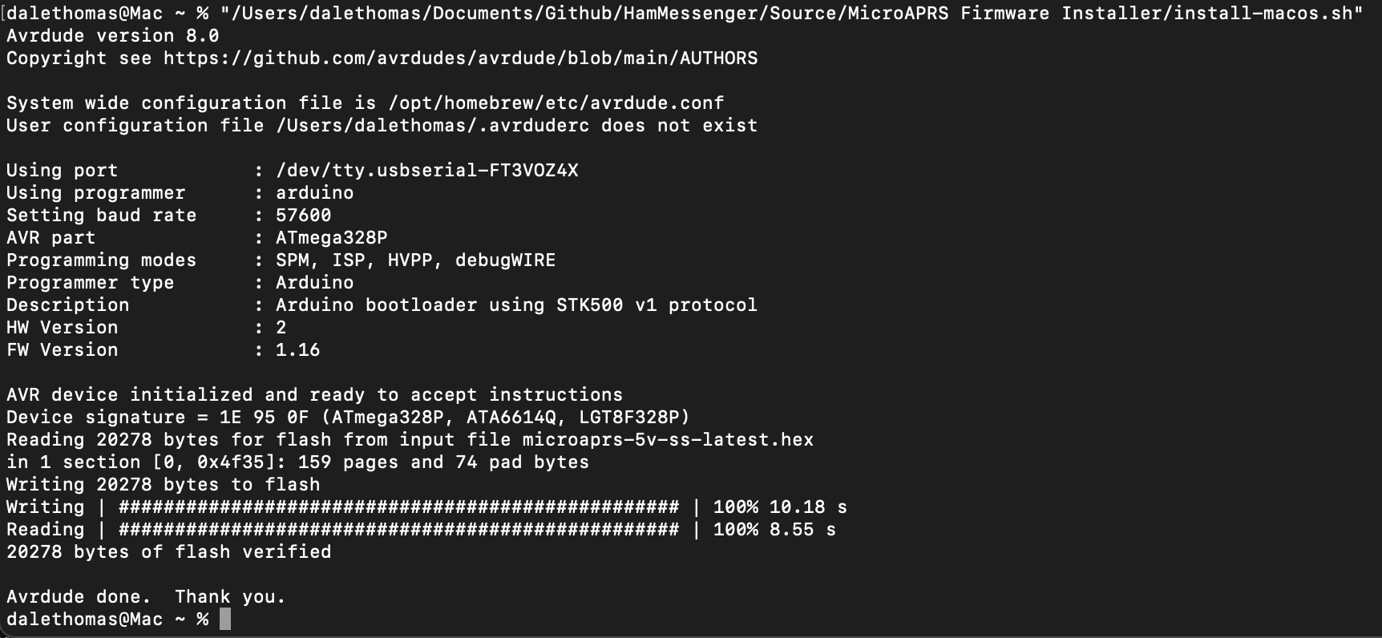
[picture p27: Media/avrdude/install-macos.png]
  

*Hint: If avrdude complains about not being able to sync, you may need to manually hit the reset button on your Arduino Pro-Mini.*

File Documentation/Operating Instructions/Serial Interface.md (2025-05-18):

# Serial Interface #

HamMessenger can be operated from a serial interface by connecting the USB port to a personal computer and using a terminal application like [PuTTY](https://www.putty.org), [RealTerm](https://sourceforge.net/projects/realterm/), or the built in serial monitor of the [Arduino IDE](https://www.arduino.cc/en/Tutorial/getting-started-with-ide-v2/ide-v2-serial-monitor).  

In the 2025 release of HamMessenger, there is now a dedicated GUI app that will run in Windows or MacOS (Python) and allows full control of HamMessenger. There is even a nice map that will show the realtime location of stations.  

## Commands ##

Here are a list of commands supported by HamMessenger.

Command | Description | Example
--- | --- | :---
__?__ | Displays serial command examples
__CMD:Settings:Print:__ | Prints the current settings
__CMD:Settings:Save:__ | Saves settings to EEPROM
__CMD:Beacon:__ | Immediately transmits a beacon
__CMD:Message:<Recipient Callsign>:<Recipient SSID>:<Message>"__ | Sends a message to a recipient
__CMD:SD:Raw:Print:__ | Prints all raw data saved in raw.txt on the SD card
__CMD:SD:Raw:Delete:__ | Deletes all raw data saved in raw.txt on the SD card
__CMD:SD:Msg:Print:__ | Prints all messages saved in msg.txt on the SD card
__CMD:SD:Msg:Delete:__ | Delete all messages saved in msg.txt on the SD card
__CMD:Modem:<command>__ | Writes commands directly to the modem. See https://github.com/markqvist/MicroAPRS#serial-commands | CMD:Modem:cNOCALL
&nbsp;
__CMD:Settings:APRS:Beacon Enabled:<True/False>__ | When true, a beacon is automatically transmitted | True (1)
__CMD:Settings:APRS:Beacon Distance:<-3.4028235E+38 to 3.4028235E+38>__ | Distance that a beacon is transmitted in miles | 0.5
__CMD:Settings:APRS:Beacon Idle Time:<0 to 4,294,967,295>__ | Time that the station can be idle in a location before a beacon is transmitted in milliseconds | 60000
__CMD:Settings:APRS:Raw Packet:<alphanumeric 99 char max>__ | !:ZZ5ABC-1 :Hi there!{01 | See https://aprs.fi/?c=raw&call= (login required)
__CMD:Settings:APRS:Comment:<alphanumeric 99 char max>__ | APRS comment | https://github.com/dalethomas81/HamMessenger
__CMD:Settings:APRS:Message:<alphanumeric 99 char max>__ | APRS message to recipient | Hi!
__CMD:Settings:APRS:Recipient Callsign:<alphanumeric 6 char max>__ | Callsign of the recipient | NOCALL
__CMD:Settings:APRS:Recipient SSID:<alphanumeric 1 char max>__ | SSID of recipient i.e. the number 3 in 'NOCALL-3' | 3
__CMD:Settings:APRS:My Callsign:<alphanumeric 6 char max>__ | Callsign of the sender (me) | NOCALL
__CMD:Settings:APRS:Callsign SSID:<alphanumeric 1 char max>__ | SSID of the sender i.e. the number 4 in 'NOCALL-4' | 4
__CMD:Settings:APRS:Dest Callsign:<alphanumeric 6 char max>__ | Callsign of destination when sending | APRS
__CMD:Settings:APRS:Dest SSID:<alphanumeric 1 char max>__ | SSID if the destination station | 0
__CMD:Settings:APRS:PATH1 Callsign:<alphanumeric 6 char max>__ | http://wa8lmf.net/DigiPaths/ | WIDE1
__CMD:Settings:APRS:PATH1 SSID:<alphanumeric 1 char max>__ | http://wa8lmf.net/DigiPaths/ | 1
__CMD:Settings:APRS:PATH2 Callsign:<alphanumeric 6 char max>__ | http://wa8lmf.net/DigiPaths/ | WIDE2
__CMD:Settings:APRS:PATH2 SSID:<alphanumeric 1 char max>__ | http://wa8lmf.net/DigiPaths/ | 2
__CMD:Settings:APRS:Symbol:<alphanumeric 1 char max>__ | http://www.aprs.net/vm/DOS/SYMBOLS.HTM | n (node) 
__CMD:Settings:APRS:Table:<alphanumeric 1 char max>__ | 's' or 'a' (standard or alternate) | s
__CMD:Settings:APRS:Automatic ACK:<True/False>__ | Dictates if the modem will automatically ack messages | True (1)
__CMD:Settings:APRS:Preamble:<0 to 65,535>__ | Number of milliseconds of grey noise before APRS message |350
__CMD:Settings:APRS:Tail:<0 to 65,535>__ | Number of milliseconds of grey noise after APRS message | 80
__CMD:Settings:APRS:Retry Count:<0 to 65,535>__ | How many times HamMessenger will retry a message send | 2
__CMD:Settings:APRS:Retry Interval:<0 to 65,535>__ | Number of milliseconds in between message retries| 10000
&nbsp;
__CMD:Settings:GPS:Pos Tolerance:<-3.4028235E+38 to 3.4028235E+38>__ | GPS position must change this much in degrees to register as a change | 0.1
__CMD:Settings:GPS:Dest Latitude:<-3.4028235E+38 to 3.4028235E+38>__ | GPS latitude coordinates of destination | 51.508131
__CMD:Settings:GPS:Dest Longitude:<-3.4028235E+38 to 3.4028235E+38>__ | GPS longitude coordinates of destination | -0.128002
&nbsp;
__CMD:Settings:Display:Timeout:<0 to 4,294,967,295>__ | Amount of time before displays timeout and go to sleep | 120000
__CMD:Settings:Display:Brightness:<0 to 100>__ | Brightness of Oled (0 is as dim but not off) | 100%
__CMD:Settings:Display:Show Position:<True/False>__ | Lat and Long position is shown on screen | True (1)
__CMD:Settings:Display:Scroll Messages:<True/False>__ | Messages are scrolled on Message display | True (1)
__CMD:Settings:Display:Scroll Speed:<0 to 65,535>__ | Speed in milliseconds that each pixel of messages is scrolled | 4
__CMD:Settings:Display:Invert:<True/False>__ | The colors of the display will be inverted | False

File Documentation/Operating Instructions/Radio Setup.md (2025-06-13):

# Radio Setup #

To be able to transmit on your radio using HamMessenger, you will need to properly set up your radio. This document will describe how to do that.  

## Choosing a radio ##

My preferred radio is the Baofeng UV-5R5. You can buy this radio for about $25-$30 from [Amazon](https://www.amazon.com/BAOFENG-Two-Way-136-174MHz-400-520MHz-Battery/dp/B091YLJ6CN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). I recommend the 2-pack.  

There are also slightly nicer versions of this radio that you can buy directly from [BTECH](https://baofengtech.com). The [BF-F8HP](https://baofengtech.com/product/bf-f8hp/) is the 8 watt version and the [UV-5X3](https://baofengtech.com/product/uv-5x3/) is the tri-band version.  

You can also use many others radios with HamMessenger - you will just need to use a different cable between HamMessenger and the radio.  

## Frequency ##

Technically, there is no reason that you can't use just about any frequency that you would like with HamMessenger. However, the agreed upon frequency for 2 meter APRS (the protcol that HamMessenger uses) is 144.390 Mhz. Using this frequency will give you the most benefit because you will be able to communicate with other stations and even be able to hit APRS repeaters.  

## Programming ##

To program the UV-5R5 (or the other 2 variants above), you can use an open source program called [CHIRP](https://chirp.danplanet.com/projects/chirp/wiki/Home) or you can program directly from the front of the radio. I won't go into how to use CHIRP but I will show you how to program the Baofeng from the keypad. Knowing how to program it using this method will give you the most benefit as you will be able to program the radio in the field and make changes on the fly without a computer.  

### Programming a Channel Using the Keypad ###

1. First, determine the channel that you would like to program. You can do this by cycling through the radio and determining which channel is not in use.  
2. Put the radio in VFO mode by pressing the **[VFO/MR]** button. You can tell the radio is in VFO mode if there are no channel numbers displayed on the right. If there are, press the button again and you should see them disappear.  
3. Next, enter the APRS frequency so that it shows up on the display. Note: pay attention here to what VFO you are using. You can tell by the up or down arrow on the left side. It doesn't matter which one but you will want to make sure it stays the same from this point forward. You can change it using the **[A/B]** button.
4. Next, press the **[Menu]** button to get to the settings of the radio. The Baofeng gets a bad rap for having a menu system that is difficult to navigate and understand. I will tell you exactly what to enter but if you want to know more about why then hands down the best place to do that is the [Miklor](https://www.miklor.com/uv5r/UV5R-MenuDef.php) site.  
5. Lastly, follow this table to enter the correct settings for each item. Set them in this order and if they are not listed then don't worry about them. Also note that most of these are not required for APRS - some may reduce difficulties when Txing or Rxing and some just make life easier on you.  

    number | item | required | value | description
    ------ | ------- | -------- | ----- | -----------
    0 | SQL | *N* | 0 | recommended squelch (0 will open it all the way)
    2 | TXP | *N* | HIGH | transmit power
    3 | SAVE | *N* | OFF | power save mode
    4 | VOX | *N* | OFF | voice activation
    5 | WN | **Y** | NARR | bandwidth
    7 | TDR | *N* | OFF | dual watch dual reception
    9 | TOT | *N* | 60 | transmission time out time
    10 | R-DCS | **Y** | OFF | receive digital coded squelch
    11 | R-CTCS | **Y** | OFF | receive continuouse tone coded squelch
    12 | T-DCS | **Y** | OFF | transmit digital coded squelch
    13 | T-CTCS | **Y** | OFF | transmit continuouse tone coded squelch
    16 | DTMFST | *N* | OFF | DTMF tone of transmit
    19 | PTT-ID | *N* | OFF | when to send the PTT-ID
    20 | MDF-A | *N* | NAME | channel mode A display
    21 | MDF-B | *N* | NAME | channel mode B display
    23 | BCL | *N* | ON | busy channel lockout (won't interfere if someone already broadcasting)
    25 | SFT-D | **Y** | OFF | frequency shift direction
    26 | OFFSET | *N*| 000.000 | frequency shift amount
    35 | STE | *N* | OFF | squelch tail elimination
    36 | RP-STE | *N* | OFF | repeater squelch tail elimination
    37 | RPT-RL | *N* | OFF | delay the squelch tail of repeater
    39 | ROGER | *N* | OFF | tone at the end of transmission
    27 | MEM-CH | **Y** | empty channel you chose in step 1 | Note: do this last as it will trigger the save!

## Radio Use ##

I have found that the volume of the radio works well at around 80%. I actually havent done much testing here but this works well.

HamMessenger is designed so that you can wear the radio on your belt while you use HamMessenger as a texting device in your hand.

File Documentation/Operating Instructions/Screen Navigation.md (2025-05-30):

## Screen Navigation ##

-The **[Up]** and **[Down]** keys move the cursor through the selections.\
-Pressing the **[Enter]** key will navigate to the screen selected by the cursor.\
-To exit a screen, press the **[Escape]** key.
#### Editing a Setting ####
-Select the setting using the **[Up]** and **[Down]** keys.\
-Press the **[Enter]** key. This will put the device in edit mode.\
-Use the **[Up]** and **[Down]** keys to modify a boolean value.\
-Use the **[-]** key to change the sign of a float value.\
-Use the **[Backspace]** key to delete alphanumeric values and enter new values.\
-Press the **[Enter]** key to accept a new value or press the **[Escape]** key to revert to the original value.

```text
  SPLASH
┌─────────────────────────┐
│      HamMessenger       │
│                         │
│         Build           │
│ Month Day Year HH:mm:ss │
│                         │
│       Call:NOCALL       │
└───────────┬─────────────┘
            │
            │
  HOME      │                                    MESSAGES                            NEW MESSAGE
┌───────────┴─────────────┐                    ┌─────────────────────────┐         ┌─────────────────────────┐
│ Tx Rx GPS-10 5.2V 9999us│                    │ Tx Rx GPS-10 5.2V 9999us│         │ Tx Rx GPS-10 5.2V 9999us│
│       [ HOME ]          │                    │  [NOCALL-0]>[NOCALL-1]  │         │     [ NEW MESSAGE ]     │
│ >Messages<              ├──────────┬─────────┤                         ├─────────┤ >Message Text<          | 
│  Live Feed              │          │         │ Hi, Dale!               │         │  Recipient Callsign     │
│  Settings               │          │         │ Record: 1 of 100        │         │  Recipient SSID         │
│                         │          │         │ D: 110721   T: 9271700  │         │                         │
│ LT:9999.99 LG:99999.99  │          │         │ LT:9999.99 LG:99999.99  │         │  Type msg then <ENTER>_ │
└─────────────────────────┘          │         └─────────────────────────┘         └─────────────────────────┘
                                     │
                                     │
                                     │           LIVE FEED
                                     │         ┌─────────────────────────┐
                                     │         │ Tx Rx GPS-10 5.2V 9999us│
                                     │         │  [NOCALL-0]>[NOCALL-1]  │
                                     ├─────────┤                         │
                                     │         │ The weather report for F│
                                     │         │ Record: 1 of 100        │
                                     │         │ D: 110721   T: 9271700  │
                                     │         │ LT:9999.99 LG:99999.99  │
                                     │         └─────────────────────────┘
                                     │
                                     │
                                     │           SETTINGS                            APRS
                                     │         ┌─────────────────────────┐         ┌─────────────────────────┐
                                     │         │ Tx Rx GPS-10 5.2V 9999us│         │ Tx Rx GPS-10 5.2V 9999us│
                                     │         │      [ SETTINGS ]       │         │       [ APRS ]          │
                                     └─────────┤ >APRS<                  ├────┬────┤ >Beacon Enabled<        │
                                               │  GPS                    │    │    │  Beacon Distance        │
                                               │  Display                │    │    │  Beacon Idle Time       │
                                               │                         │    │    │                         │
                                               │ LT:9999.99 LG:99999.99  │    │    │  120000_                │
                                               └─────────────────────────┘    │    └─────────────────────────┘
                                                                              │
                                                                              │
                                                                              │      GPS
                                                                              │    ┌─────────────────────────┐
                                                                              │    │ Tx Rx GPS-10 5.2V 9999us│
                                                                              │    │        [ GPS ]          │
                                                                              ├────┤ >Position Tolerance<    │
                                                                              │    │  Dest Latitude          │
                                                                              │    │  Dest Longitude         │
                                                                              │    │                         │
                                                                              │    │  10000_                 │
                                                                              │    └─────────────────────────┘
                                                                              │
                                                                              │
                                                                              │      DISPLAY
                                                                              │    ┌─────────────────────────┐
                                                                              │    │ Tx Rx GPS-10 5.2V 9999us│
                                                                              │    │      [ DISPLAY ]        │
                                                                              └────┤ >Timeout<               │
                                                                                   │  Brightness             │
                                                                                   │  Show Position          │
                                                                                   │                         │
                                                                                   │  10000_                 │
                                                                                   └─────────────────────────┘

```

The above text was generated at https://asciiflow.com/

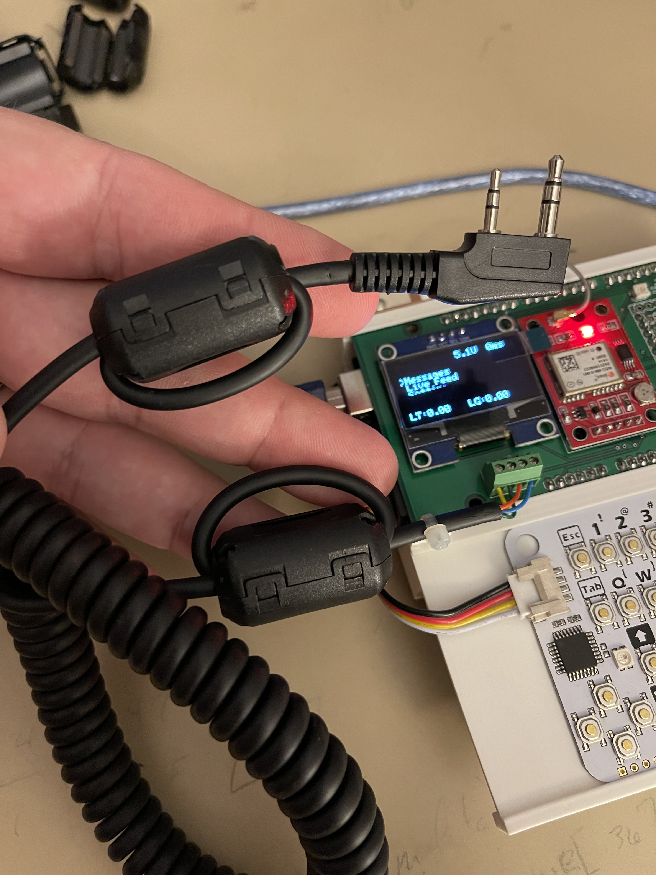
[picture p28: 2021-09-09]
Media/Install/large-ferrites.jpeg

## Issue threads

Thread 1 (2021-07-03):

Missing hardware specs

FlexGunship, 2021-07-03:
To support development of enclosures either mechanical specs for the components or references to spec sheets for the physical components is needed.

Examples below:

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

dalethomas81, 2021-07-03:
Thanks a bunch for joining the fight, @FlexGunship! The HamMessenger team can use all the help we can get.

I am in the process of designing the PCB (shield) now. I think that once that is done I will have a better idea of what the final dimensions will be.

I don't have a lot of experience with this part of the process but it seems like there should be some "final form" consideration. In my mind, I always envisioned HamMessenger looking like the old LG Envy flip phones (my first true love outside of modern touch screens) but I think we're a few iterations away from that.

God, just looking at these makes me want to browse eBay for one...
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

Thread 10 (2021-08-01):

All-in-one?

Kongduino, 2021-08-01:
Hi!

I am looking with interest at this project, and the first thought that crossed my mind was, wouldn't it be simpler to run everything on one board? After all the Mega has enough pins, and you could integrate MicroAPRS into your own code. GPL 3.0 allows for it, AFAIK.

Also, along the same lines, wouldn't an ESP32 for instance be more practical? I understand, from reading the code and docs quickly, that you need to convert to 3v3 anyway. It'd also offer more choices in terms of input: BLE, WiFi (small web server) etc.

Anyway, this looks like a great project, and I'll be watching! :-)

dalethomas81, 2021-08-02:
Hey @Kongduino, you are definitely right with most everything you said. This is one of those projects that sort of just evolved over time. I recently decided that I would open it up for others to enjoy and hack.

I truly believe that the final form of hamMessenger will look much different than it does now. I am more focused on the functionality but maybe I should take it another direction?

Hopefully, this next round of boards will be good enough that others can be comfortable enough to build it and give some feedback.

At the end of the day, this is just a hobby for me. My hope is that others with more design experience and better programming skills, such as yourself, can help shape HamMessenger into what it should be!

Kongduino, 2021-08-02:
Thanks for your kind words.

I've started reading the code, both yours and MicroAPRS, to get a better understanding. I'm not a ham radio amateur – I've been toying with the idea of getting my license, though – but work with LoRa, so we're cousins, of sorts :-)

The idea of using a pair of Baofeng and Megas is quite attractive though!

hatonthecat, 2022-12-03:
Hi Dale (and Kongduino :),

I had a similar idea, and I just got into amateur radio. I've been interested in an all-in-one, but using some of the lower bands and running it on solar ion capacitors: https://github.com/markqvist/Reticulum/discussions/171

dalethomas81, 2025-05-30:
Oh and I recently got a LoRa device but I haven't fully figured out how to maximize it yet!

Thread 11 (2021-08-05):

Raspberry Pi and sending messages?

iCrazyBlaze, 2021-08-05:
I really like the look of this project and it's clear a lot of effort went into creating it, but I would love to see the ability to hook this up to a Raspberry Pi or similar device to be able to send and receive messages through a software with some kind of UI. Will this sort of thing ever be considered for the project? I would also be really happy to see secure encryption for the protocol but that seems like it would be really difficult to implement. Looking forward to updates!

dalethomas81, 2021-08-05:
Hey @iCrazyBlaze, there is already a serial protocol so technically this is already possible! Check it out and feel free to add to it as you see fit.

Kongduino, 2021-08-05:
I have encryption working on my LoRa messenger app (AES256), so this is something I could bring to the table.

dalethomas81, 2021-08-05:
Unfortunately for amateur radio it is illegal to encrypt your communications.

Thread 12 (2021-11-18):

Cable information

JoshuaMorris, 2021-11-18:
Do you have information or a link for the cable you are using? How did you configure the PTT?

dalethomas81, 2021-11-19:
Have a look at the link below. The cable is a "2 pin Kenwood" cable and I have a link in this table. However, I will warn you that I am on the hunt for an identical cable that is shielded. The one I am using is not and it is causing issues during transmitting.

If you come across a shielded one please let me know!

https://github.com/dalethomas81/HamMessenger/blob/master/Documentation/Parts/BOMs/peripherals.md

JoshuaMorris, 2021-11-19:
I found that link but it doesn’t work for me, I get the amazing dog image on it.

dalethomas81, 2021-11-19:
Sorry about that. I tried searching on Amazon and didn't find one but I did find a similar one on eBay. Here is the link.

https://www.ebay.com/itm/2-PIN-4-WIRE-TRS-COILED-MICROPHONE-CABLE-FOR-BAOFENG-KENWOOD-WOUXUN-LLL237627001-/402691205730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

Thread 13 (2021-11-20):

Questions about interfacing to Baofeng

bettio, 2021-11-20:
Nice project, I was looking into doing something similar.
The schematics I found so far for interfacing with the Baofeng were quite different, the most important difference was about the PTT that was implemented using an audio transformer component rather the solution in your project.
Did you test also test also the audio transformer solution?  Are you aware of any pro of using the tansformer rather than your solution?

dalethomas81, 2021-11-21:
In this project, I am using the same method as the MicroAPRS (which is also where the modem firmware is from). I have not tested any other design. Can you link an example?

bettio, 2021-11-27:
> Can you link an example?

Sure: https://k0rx.com/blog/2017/11/baofeng.html

dalethomas81, 2021-11-27:
The PTT interface in this example is not implemented using an audio transformer. That is for the audio input (PC->Baofeng).

The PTT interface in this example is implemented using an optocoupler. Which is a very good idea. Basically, with an optocoupler the circuits are completely isolated. The driving circuit turns on a LED whereas the driven circuit detects the LED with a photo-resistor.

Thank you for the article. I would like to see the performance difference in the optocoupler versus the BJT method that HamMessenger is using.

bettio, 2021-11-28:
In your opinion, does using an audio transformer gives any relevant advantage over the MicroAPRS board design?

dalethomas81, 2021-11-28:
Using the audio transformer requires that you have an actual sound card. In other words a DAC (digital to analog converter).

The Arduino does not so the way the MicroAPRS is doing it is required. It uses several digital outputs to simulate a sound wave. I suppose you could add the audio transformer in addition to it though I don't know what benefit that would get you.

If you do experiment with this, please let me know the results.

I am thinking with the next iteration of the board, I may try the optocoupler design in the circuit you referenced. Would be good to experience with that vs the BJT as well.

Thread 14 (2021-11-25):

v1.1 Cir

Marshmellow84, 2021-11-25:

dalethomas81, 2021-11-25:
Hey @Marshmellow84, there are 2 places I have tried.

The first was https://oshpark.com. They build beautiful high quality boards. However, they were very expensive, the shipping time was very long, and I couldn't get a stencil.

The second place was https://jlcpcb.com. I highly recommend you buy from them. The boards are very inexpensive, the shipping was way faster, and they sell stencils.

Btw, if you don't know, a stencil is a "mask" you can put over the board so that you can easily apply the solder paste to only the right places. Check out this video: https://youtu.be/fYInlAmPnGo

Marshmellow84, 2021-11-25:
Its been years since I did any of the stencil stuff. I was hoping some were already made up. However, that said I did look over the buy list last night briefly, but don't recall the stencil in there. Perhaps I missed it?
 I'm guessing if I place a order just upload a stencil to them and they do the rest on the order?

dalethomas81, 2021-11-25:
Oh man, if I had the time I would make some up to sell. Actually, I think jlcpcb has a service that will solder the boards for you. Not sure about that.

For the stencil, when you upload the gerber files for the pcb to them they give you the option to buy a stencil at the same time you checkout. They build the stencil based on the gerber file.

Marshmellow84, 2021-11-25:
Oh nice, okay I will do that then.  And I don't mind making it myself, I look forward to that part. Just was hung up on the board itself so ty for the help ill keep ya posted as I go

dalethomas81, 2025-05-30:
Hey @Marshmellow84 did you ever get any of these built?

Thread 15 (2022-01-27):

Like to get 6 new second generation boards

Blainea2022, 2022-01-27:
Dale, I read your article in IEEE "Spectrum".  Is there any way that I can get 6 of your 2nd generation PC boards?  It is part of emergency communications network that I would like to put in place for my community.

Thanks,

Blainea2022

dalethomas81, 2022-01-27:
Hey Blainea2022 - do you mean 6 fully assembled boards or just the PCBs? I assume you mean PCBs. If so, I may have a few laying around that I could send you.

However, you do realize that you can also order these boards yourself. The Eagle files can be found at this link: https://github.com/dalethomas81/HamMessenger/tree/master/Documentation/CAD/Eagle

Sent from my iPhone

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

dalethomas81, 2022-01-27:
Also, let me note that I do not recommend relying on HamMessenger for emergency communications. It is not robust and developed enough for something like that.

Nothing beats a good old analog handheld in an emergency:)

Sent from my iPhone

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
>>> On Jan 26, 2022, at 9:40 PM, Blainea2022 ***@***.***> wrote:
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

Blainea2022, 2022-01-29:
Dale, thank you for getting back.   I went to the Eagle folders and got confused, do I send the Gerber files or the Shield_2021-07-24.zip to PCBWay?  I am so far behind the times that I don’t understand what programs are available for layout a PCB and what different companies work with.

Thanks for your input on emergency communications.  Maybe my challenge would be to harden your project for my needs.   I have limited experience with WinLink.  I use my laptop, a Arduino (tiny) modem, and 2 meter handheld FM transceiver on packet. But in the emergency mode I need my back up generator to keep it all going on WinLink.  That is a lot of investment for each station.  I think I can run yours from a car battery for long time and each station is about 300 hundred dollars.  Getting an 80 character message through seems much easier than WinLink.  Unlike audio there is a record on SD card.

If you would like I can send some real “green stuff” to cover your expenses.

Thanks again
Blaine Anderson
1345 North 2550 East
Layton,  UT 84040-2733

Sent from Mail<https://go.microsoft.com/fwlink/?LinkId=550986> for Windows

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

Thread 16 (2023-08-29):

Opto isolate ptt? And other stuff

jleonards1, 2023-08-29:
Saw you had some issues with spikes.  Not sure which line they are coming on but you could try opto isolate the ptt line.  Are the Rx and TX also digital serial data to /from the radio?

on a separate note I’m new to ham and looking for a solution for monitoring temperature remotely.  I’m not sure the best way to do this but have arduino mega and some uv5r laying around.  Was thinking initially of having the mega broadcast and 440hz tone over the mic channel once a temp threshold is hit.  But would be cooler if I could send a 10 character message over gmrs or even a murs channel with actual temp data.  Any thoughts on a good way to do it?

thanks for the cool project

ms48083, 2023-08-29:
I did a remote temperature monitoring project with an arduino and 4 ds18b20 sensors. But I used wifi to send the data to a hosted mysql database. Maybe not how you want to do it, but I'm happy to share the details. MikeKe8tkc

  On Tue, Aug 29, 2023 at 12:27 AM, ***@***.***> wrote:

Saw you had some issues with spikes. Not sure which line they are coming on but you could try opto isolate the ptt line. Are the Rx and TX also digital serial data to /from the radio?

on a separate note I’m new to ham and looking for a solution for monitoring temperature remotely. I’m not sure the best way to do this but have arduino mega and some uv5r laying around. Was thinking initially of having the mega broadcast and 440hz tone over the mic channel once a temp threshold is hit. But would be cooler if I could send a 10 character message over gmrs or even a murs channel with actual temp data. Any thoughts on a good way to do it?

thanks for the cool project

—
Reply to this email directly, view it on GitHub, or unsubscribe.
You are receiving this because you are subscribed to this thread.Message ID: ***@***.***>

jleonards1, 2023-10-05:
Hello,I have made a simple LORA transmitter and receiver pair but still want to try HAM.  I was looking for schematics of how you connect to the UV5R?  Are they posted somewhere and I missed them?Thanks!Jerry LeonardsSent from my iPhoneOn Aug 29, 2023, at 4:39 AM, Mike Schwedt ***@***.***> wrote:
I did a remote temperature monitoring project with an arduino and 4 ds18b20 sensors. But I used wifi to send the data to a hosted mysql database. Maybe not how you want to do it, but I'm happy to share the details. MikeKe8tkc

  On Tue, Aug 29, 2023 at 12:27 AM, ***@***.***> wrote:

Saw you had some issues with spikes. Not sure which line they are coming on but you could try opto isolate the ptt line. Are the Rx and TX also digital serial data to /from the radio?

on a separate note I’m new to ham and looking for a solution for monitoring temperature remotely. I’m not sure the best way to do this but have arduino mega and some uv5r laying around. Was thinking initially of having the mega broadcast and 440hz tone over the mic channel once a temp threshold is hit. But would be cooler if I could send a 10 character message over gmrs or even a murs channel with actual temp data. Any thoughts on a good way to do it?

thanks for the cool project

—

Reply to this email directly, view it on GitHub, or unsubscribe.

You are receiving this because you are subscribed to this thread.Message ID: ***@***.***>

—Reply to this email directly, view it on GitHub, or unsubscribe.You are receiving this because you authored the thread.Message ID: ***@***.***>

dalethomas81, 2023-10-05:
Hey, Jerry - the schematics are posted here at this link: HamMessenger/Documentation/Schematics/Shield.pdf at master · dalethomas81/HamMessengergithub.comThe terminal connector J3 on HamMessenger allows you to attach whatever radio you want to it. Here’s a link to an image that shows the Baofeng connector pin out: XZddXJPEG Image · 21 KBSent from my iPadOn Oct 4, 2023, at 5:48 PM, jleonards1 ***@***.***> wrote:
Hello,I have made a simple LORA transmitter and receiver pair but still want to try HAM.  I was looking for schematics of how you connect to the UV5R?  Are they posted somewhere and I missed them?Thanks!Jerry LeonardsSent from my iPhoneOn Aug 29, 2023, at 4:39 AM, Mike Schwedt ***@***.***> wrote:

I did a remote temperature monitoring project with an arduino and 4 ds18b20 sensors. But I used wifi to send the data to a hosted mysql database. Maybe not how you want to do it, but I'm happy to share the details. MikeKe8tkc

  On Tue, Aug 29, 2023 at 12:27 AM, ***@***.***> wrote:

Saw you had some issues with spikes. Not sure which line they are coming on but you could try opto isolate the ptt line. Are the Rx and TX also digital serial data to /from the radio?

on a separate note I’m new to ham and looking for a solution for monitoring temperature remotely. I’m not sure the best way to do this but have arduino mega and some uv5r laying around. Was thinking initially of having the mega broadcast and 440hz tone over the mic channel once a temp threshold is hit. But would be cooler if I could send a 10 character message over gmrs or even a murs channel with actual temp data. Any thoughts on a good way to do it?

thanks for the cool project

—

Reply to this email directly, view it on GitHub, or unsubscribe.

You are receiving this because you are subscribed to this thread.Message ID: ***@***.***>

—Reply to this email directly, view it on GitHub, or unsubscribe.You are receiving this because you authored the thread.Message ID: ***@***.***>

—Reply to this email directly, view it on GitHub, or unsubscribe.You are receiving this because you are subscribed to this thread.Message ID: ***@***.***>

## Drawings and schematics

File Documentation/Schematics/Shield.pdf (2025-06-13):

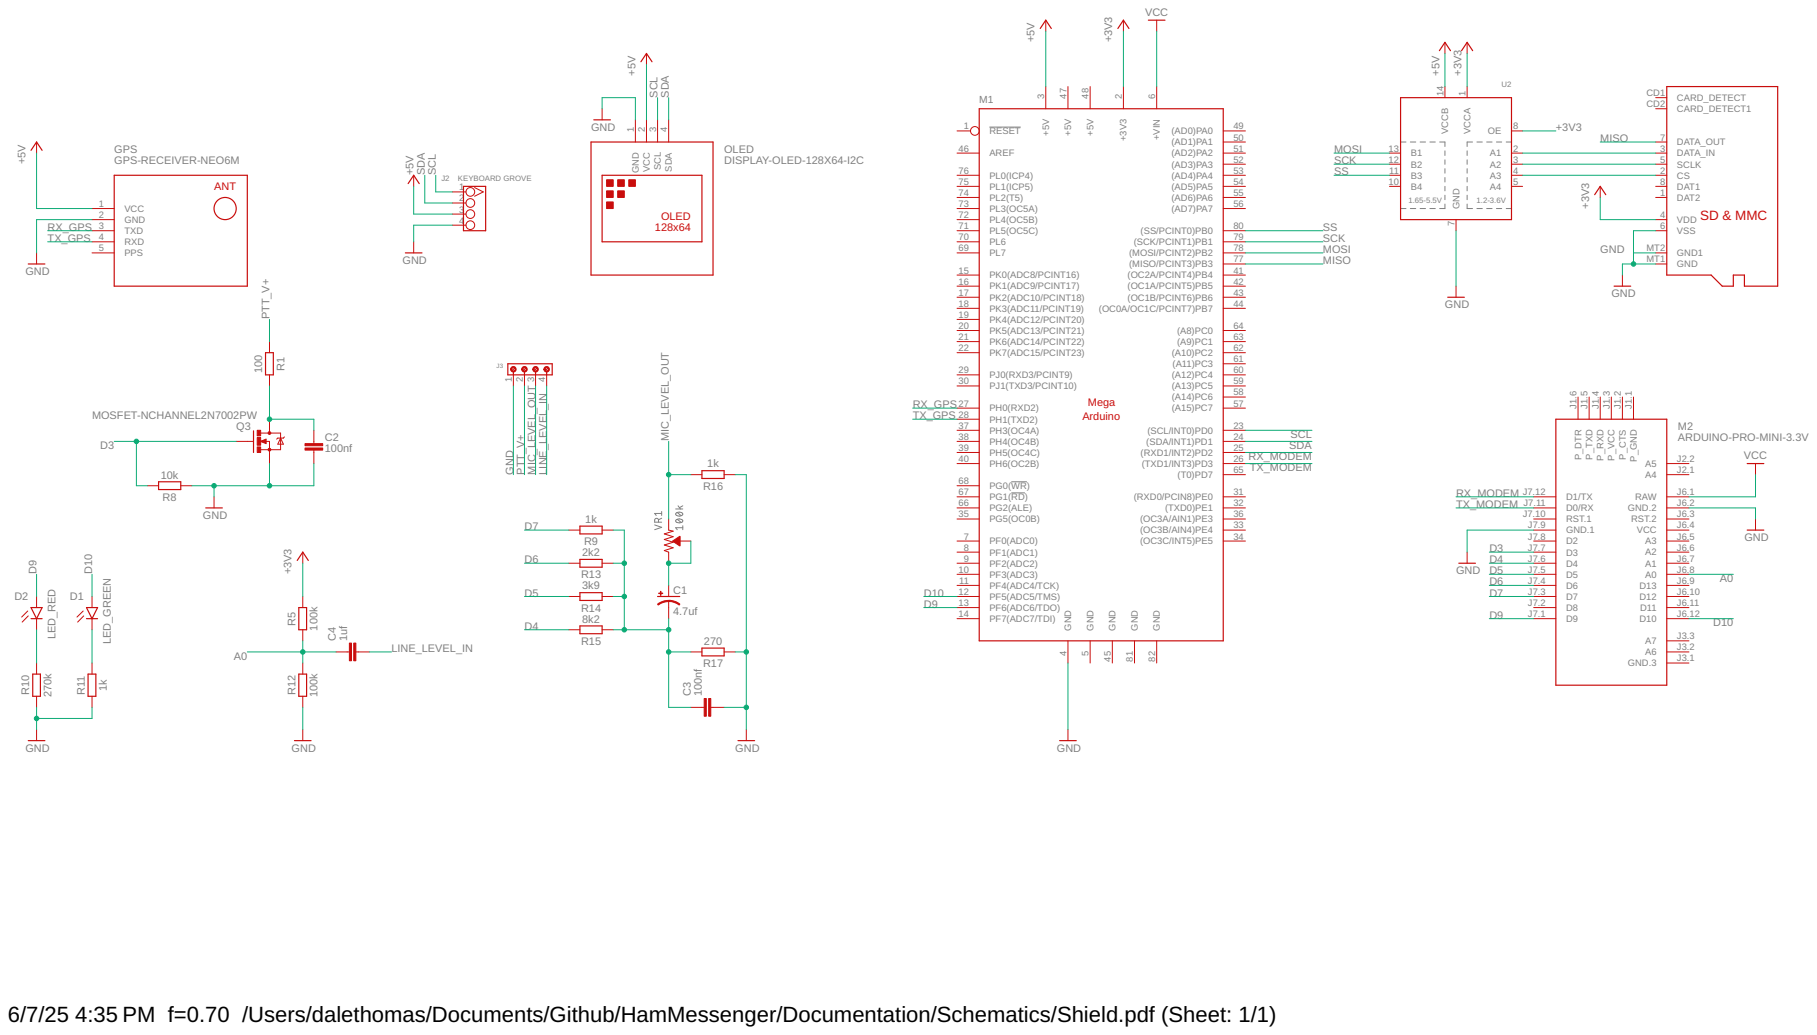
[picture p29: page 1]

6/7/25 4:35 PM f=0.70 /Users/dalethomas/Documents/Github/HamMessenger/Documentation/Schematics/Shield.pdf (Sheet: 1/1)

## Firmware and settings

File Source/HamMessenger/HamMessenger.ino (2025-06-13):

/*

  https://github.com/dalethomas81/HamMessenger
  Copyright (C) 2021  Dale Thomas

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
  DaleThomas@me.com

*/

const char version[] = __DATE__ " " __TIME__; 

#pragma region "STRUCTURES"

  // for some reason Ardunio will not allow a structure after a method
  struct APRSFormat_Raw {
    char src[15];
    char dst[15];
    char path[10];
    char data[125];
    uint32_t DateInt;
    uint32_t TimeInt;
  };

  struct APRSFormat_Msg {
    char from[15] = {'\0'};
    char to[15] = {'\0'};
    char msg[100] = {'\0'};
    int line = 0;
    bool ack = false;
    uint32_t DateInt;
    uint32_t TimeInt;
  };

  struct GPS_Date {
    byte Day = 1;
    byte Month = 1;
    int Year = 1970;
    uint32_t DateInt;
    //char DateString[9];
  };

  struct GPS_Time {
    byte Hour = 0;
    byte Minute = 0;
    byte Second = 0;
    byte CentiSecond = 0;
    uint32_t TimeInt;
    //char TimeString[9];
  };

  struct GPS {
    byte Satellites;
    GPS_Date Date;
    GPS_Time Time;
  } GPSData;

#pragma endregion

#pragma region "UTILITY"

  #define BATT_CHARGED            7200
  #define BATT_DISCHARGED         5600
  #define VOLTAGE_CHECK_RATE      10000

  unsigned char VoltagePercent = 0;
  long Voltage = 0;
  unsigned long voltage_check_timer;
  unsigned long processor_scan_time, scanTime;

  long readVcc(){
    // Read 1.1V reference against AVcc
    // set the reference to Vcc and the measurement to the internal 1.1V reference
    #if defined(__AVR_ATmega32U4__) || defined(__AVR_ATmega1280__) || defined(__AVR_ATmega2560__)
      ADMUX = _BV(REFS0) | _BV(MUX4) | _BV(MUX3) | _BV(MUX2) | _BV(MUX1);
    #elif defined (__AVR_ATtiny24__) || defined(__AVR_ATtiny44__) || defined(__AVR_ATtiny84__)
      ADMUX = _BV(MUX5) | _BV(MUX0);
    #elif defined (__AVR_ATtiny25__) || defined(__AVR_ATtiny45__) || defined(__AVR_ATtiny85__)
      ADMUX = _BV(MUX3) | _BV(MUX2);
    #else
      ADMUX = _BV(REFS0) | _BV(MUX3) | _BV(MUX2) | _BV(MUX1);
    #endif  

    delay(2); // Wait for Vref to settle
    ADCSRA |= _BV(ADSC); // Start conversion
    while (bit_is_set(ADCSRA,ADSC)); // measuring

    uint8_t low  = ADCL; // must read ADCL first - it then locks ADCH  
    uint8_t high = ADCH; // unlocks both

    long result = (high<<8) | low;

    result = 1125300L / result; // Calculate Vcc (in mV); 1125300 = 1.1*1023*1000
    return result; // Vcc in millivolts
  }

  void handleVoltage(){
    if (millis() - voltage_check_timer > VOLTAGE_CHECK_RATE){
      Voltage = readVcc();
      VoltagePercent = constrain(map(Voltage,(int)BATT_DISCHARGED,(int)BATT_CHARGED,0,100),0,100);
      voltage_check_timer = millis();
    }
  }

  void handleStats(){
    scanTime = micros() - processor_scan_time;
    processor_scan_time = micros();
  }

#pragma endregion

#pragma region "KEYBOARD"

  // M5Stack Keyboard https://docs.m5stack.com/en/unit/cardkb
  #include <Wire.h> 
  #define CARDKB_ADDR 0x5F  
  char keyboardInputChar;
  bool wakeDisplay = false;
  bool displayDim = false;

  #define KEYBOARD_NUMBER_KEYS            (keyboardInputChar >= 48 && keyboardInputChar <= 57)
  #define KEYBOARD_DIRECTIONAL_KEYS       (keyboardInputChar >= -76 && keyboardInputChar <= -73)
  #define KEYBOARD_PRINTABLE_CHARACTERS   (keyboardInputChar >= 32 && keyboardInputChar <= 126)
  #define KEYBOARD_BACKSPACE_KEY          8
  #define KEYBOARD_ENTER_KEY              13
  #define KEYBOARD_ESCAPE_KEY             27
  #define KEYBOARD_MINUS_KEY              45
  #define KEYBOARD_PERIOD_KEY             46
  #define KEYBOARD_RIGHT_KEY              -73
  #define KEYBOARD_DOWN_KEY               -74
  #define KEYBOARD_UP_KEY                 -75
  #define KEYBOARD_LEFT_KEY               -76
  
  void handleKeyboard(){
  keyboardInputChar = 0;
  Wire.requestFrom(CARDKB_ADDR, 1);
  while(Wire.available())
  {
    char c = Wire.read();
    if (c != 0)
    {
      //Serial.println((int)c);
      if (!displayDim) { // key presses should only register if screen awake
        keyboardInputChar = c;
      }
      wakeDisplay = true;
    }
  }
}

#pragma endregion

#pragma region "SETTINGS"

  #include <EEPROM.h>

  const char Initialized[] = {"Initialized 2025JUN11 v1"}; // change this to something unique if you want to re-init the EEPROM during flashing. useful when there has been a change to a settings array.

  #define EEPROM_SETTINGS_START_ADDR      1000

  // NOTE: these need to stay in contiguous order starting at 0.
  // otherwise the getDataTypeExample will break.
  // if changes are made here, just be sure to update that function.
  #define SETTINGS_EDIT_TYPE_NONE         0
  #define SETTINGS_EDIT_TYPE_BOOLEAN      1
  #define SETTINGS_EDIT_TYPE_INT          2
  #define SETTINGS_EDIT_TYPE_UINT         3
  #define SETTINGS_EDIT_TYPE_LONG         4
  #define SETTINGS_EDIT_TYPE_ULONG        5
  #define SETTINGS_EDIT_TYPE_FLOAT        6
  #define SETTINGS_EDIT_TYPE_STRING2      7
  #define SETTINGS_EDIT_TYPE_STRING3      8
  #define SETTINGS_EDIT_TYPE_STRING7      9
  #define SETTINGS_EDIT_TYPE_STRING100    10
  #define SETTINGS_EDIT_TYPE_ALT1         11
                          
  const char *MenuItems_Settings[] = {"APRS", "GPS", "Display"};
  const char *MenuItems_Settings_APRS[] = {"Beacon Enabled", "Beacon Distance", "Beacon Idle Time", "Raw Packet", "Comment",
                                          "Message Text", "Recipient Callsign", "Recipient SSID", "My Callsign", "My SSID", 
                                          "Dest Callsign", "Dest SSID", "PATH1 Callsign", "PATH1 SSID", "PATH2 Callsign", "PATH2 SSID",
                                          "Symbol", "Table", "Automatic ACK", "Preamble", "Tail", "Retry Count", "Retry Interval"};
  const char *MenuItems_Settings_GPS[] = {"Pos Tolerance", "Dest Latitude", "Dest Longitude"};
  const char *MenuItems_Settings_Display[] = {"Timeout", "Brightness", "Show Position", "Scroll Messages", "Scroll Speed", "Invert"};

  unsigned char Settings_Type_APRS[] = {SETTINGS_EDIT_TYPE_BOOLEAN, SETTINGS_EDIT_TYPE_FLOAT, SETTINGS_EDIT_TYPE_ULONG, SETTINGS_EDIT_TYPE_STRING100, SETTINGS_EDIT_TYPE_STRING100,
                                        SETTINGS_EDIT_TYPE_STRING100, SETTINGS_EDIT_TYPE_STRING7, SETTINGS_EDIT_TYPE_STRING3, SETTINGS_EDIT_TYPE_STRING7, SETTINGS_EDIT_TYPE_STRING3,
                                        SETTINGS_EDIT_TYPE_STRING7, SETTINGS_EDIT_TYPE_STRING3, SETTINGS_EDIT_TYPE_STRING7, SETTINGS_EDIT_TYPE_STRING3, SETTINGS_EDIT_TYPE_STRING7, SETTINGS_EDIT_TYPE_STRING3,
                                        SETTINGS_EDIT_TYPE_STRING2, SETTINGS_EDIT_TYPE_ALT1, SETTINGS_EDIT_TYPE_BOOLEAN, SETTINGS_EDIT_TYPE_UINT, SETTINGS_EDIT_TYPE_UINT, SETTINGS_EDIT_TYPE_UINT, SETTINGS_EDIT_TYPE_UINT};
  unsigned char Settings_Type_GPS[] = {SETTINGS_EDIT_TYPE_FLOAT, SETTINGS_EDIT_TYPE_FLOAT, SETTINGS_EDIT_TYPE_FLOAT};
  unsigned char Settings_Type_Display[] = {SETTINGS_EDIT_TYPE_ULONG, SETTINGS_EDIT_TYPE_UINT, SETTINGS_EDIT_TYPE_BOOLEAN, SETTINGS_EDIT_TYPE_BOOLEAN, SETTINGS_EDIT_TYPE_UINT, SETTINGS_EDIT_TYPE_BOOLEAN};
  unsigned char Settings_TypeIndex_APRS[] = { 0,0,0,0,1,
                                              2,0,0,1,1,
                                              2,2,3,3,4,4,
                                              0,1,3,0,1,2,3}; // this is the index in the array of the data arrays below
  unsigned char Settings_TypeIndex_GPS[] = {1,2,3};
  unsigned char Settings_TypeIndex_Display[] = {1,4,2,3,5,4};
  // data arrays
  bool Settings_TypeBool[5] = {true,true,true,true,false}; // aprs beacon enabled, display show position, scroll messages, auto ACK, invert
  int Settings_TypeInt[0] = {};
  unsigned int Settings_TypeUInt[6] = {100,400,80,4,5,10000}; // display brightness, aprs preamble, aprs tail, scroll speed, Retry Count, Retry Interval
  long Settings_TypeLong[0] = {};
  unsigned long Settings_TypeULong[2] = {300000, 2000}; // aprs beacon Idle Time, display timeout
  float Settings_TypeFloat[4] = {1.00000,0.00001,34.790040,-82.790672}; // aprs beacon distance, gps position tolerance, gps latitude, gps longitude
  char Settings_TypeString2[2][2] = {'n','\0'};
  char Settings_TypeString3[5][3] = {'0','0','\0'};
  char Settings_TypeString7[5][7] = {'N','O','C','A','L','L','\0'};
  char Settings_TypeString100[3][100] = {'T','e','s','t','\0'};
  char Settings_TempDispCharArr[100];

  #define SETTINGS_APRS_BEACON_ENABLED          Settings_TypeBool[Settings_TypeIndex_APRS[0]]         // beacon enabled
  #define SETTINGS_APRS_BEACON_DISTANCE         Settings_TypeFloat[Settings_TypeIndex_APRS[1]]        // beacon distance
  #define SETTINGS_APRS_BEACON_IDLE_TIME        Settings_TypeULong[Settings_TypeIndex_APRS[2]]        // beacon idle time
  #define SETTINGS_APRS_RAW_PACKET              Settings_TypeString100[Settings_TypeIndex_APRS[3]]    // raw packet
  #define SETTINGS_APRS_COMMENT                 Settings_TypeString100[Settings_TypeIndex_APRS[4]]    // comment
  #define SETTINGS_APRS_MESSAGE                 Settings_TypeString100[Settings_TypeIndex_APRS[5]]    // message
  #define SETTINGS_APRS_RECIPIENT_CALL          Settings_TypeString7[Settings_TypeIndex_APRS[6]]      // recipient
  #define SETTINGS_APRS_RECIPIENT_SSID          Settings_TypeString3[Settings_TypeIndex_APRS[7]]      // recipient ssid
  #define SETTINGS_APRS_CALLSIGN                Settings_TypeString7[Settings_TypeIndex_APRS[8]]      // callsign
  #define SETTINGS_APRS_CALLSIGN_SSID           Settings_TypeString3[Settings_TypeIndex_APRS[9]]      // callsign ssid
  #define SETTINGS_APRS_DESTINATION_CALL        Settings_TypeString7[Settings_TypeIndex_APRS[10]]     // Destination Callsign
  #define SETTINGS_APRS_DESTINATION_SSID        Settings_TypeString3[Settings_TypeIndex_APRS[11]]     // Destination SSID
  #define SETTINGS_APRS_PATH1_CALL              Settings_TypeString7[Settings_TypeIndex_APRS[12]]     // PATH1 Callsign
  #define SETTINGS_APRS_PATH1_SSID              Settings_TypeString3[Settings_TypeIndex_APRS[13]]     // PATH1 SSID
  #define SETTINGS_APRS_PATH2_CALL              Settings_TypeString7[Settings_TypeIndex_APRS[14]]     // PATH2 Callsign
  #define SETTINGS_APRS_PATH2_SSID              Settings_TypeString3[Settings_TypeIndex_APRS[15]]     // PATH2 SSID
  #define SETTINGS_APRS_SYMBOL                  Settings_TypeString2[Settings_TypeIndex_APRS[16]]     // Symbol
  #define SETTINGS_APRS_SYMBOL_TABLE            Settings_TypeString2[Settings_TypeIndex_APRS[17]]     // Symbol Table
  #define SETTINGS_APRS_AUTOMATIC_ACK           Settings_TypeBool[Settings_TypeIndex_APRS[18]]        // Automatic ACK
  #define SETTINGS_APRS_PREAMBLE                Settings_TypeUInt[Settings_TypeIndex_APRS[19]]        // Preamble
  #define SETTINGS_APRS_TAIL                    Settings_TypeUInt[Settings_TypeIndex_APRS[20]]        // Tail
  #define SETTINGS_APRS_RETRY_COUNT             Settings_TypeUInt[Settings_TypeIndex_APRS[21]]        // Retry Count
  #define SETTINGS_APRS_RETRY_INTERVAL          Settings_TypeUInt[Settings_TypeIndex_APRS[22]]        // Retry Interval

  #define SETTINGS_GPS_POSITION_TOLERANCE       Settings_TypeFloat[Settings_TypeIndex_GPS[0]]         // position tolerance
  #define SETTINGS_GPS_DESTINATION_LATITUDE     Settings_TypeFloat[Settings_TypeIndex_GPS[1]]         // destination latitude
  #define SETTINGS_GPS_DESTINATION_LONGITUDE    Settings_TypeFloat[Settings_TypeIndex_GPS[2]]         // destination longitute

  #define SETTINGS_DISPLAY_TIMEOUT              Settings_TypeULong[Settings_TypeIndex_Display[0]]      // timeout
  #define SETTINGS_DISPLAY_BRIGHTNESS           Settings_TypeUInt[Settings_TypeIndex_Display[1]]       // brightness
  #define SETTINGS_DISPLAY_SHOW_POSITION        Settings_TypeBool[Settings_TypeIndex_Display[2]]       // show position
  #define SETTINGS_DISPLAY_SCROLL_MESSAGES      Settings_TypeBool[Settings_TypeIndex_Display[3]]       // scroll messages
  #define SETTINGS_DISPLAY_SCROLL_SPEED         Settings_TypeUInt[Settings_TypeIndex_Display[4]]       // scroll speed
  #define SETTINGS_DISPLAY_INVERT               Settings_TypeBool[Settings_TypeIndex_Display[5]]       // invert

  bool applySettings=false, saveModemSettings=false;
  unsigned char applySettings_Seq=0;
  bool modemCmdFlag_Setc=false, modemCmdFlag_Setsc=false;
  bool modemCmdFlag_Setd=false, modemCmdFlag_Setsd=false;
  bool modemCmdFlag_Set1=false, modemCmdFlag_Sets1=false;
  bool modemCmdFlag_Set2=false, modemCmdFlag_Sets2=false;
  bool modemCmdFlag_Setls=false, modemCmdFlag_Setlt=false;
  bool modemCmdFlag_Setma=false, modemCmdFlag_Setw=false;
  bool modemCmdFlag_SetW=false, modemCmdFlag_Setmr=false;
  bool modemCmdFlag_SetS=false, modemCmdFlag_SetC=false;
  bool modemCmdFlag_SetH=false;
  
  #if !defined(ARRAY_SIZE)
      #define ARRAY_SIZE(x) (sizeof((x)) / sizeof((x)[0]))
  #endif

  void checkInit(){
    Serial.println(F("Checking initialization...")); // `F()` stores the string in flash memory and avoids heaps
    bool writeDefaults = false;
    for (byte i=0;i<sizeof(Initialized)-1;i++){
      if (Initialized[i] != EEPROM.read(i)) {
        writeDefaults = true;
        i = sizeof(Initialized); // get out
      }
    }
    /*for (byte i=0;i<sizeof(version)-1;i++){
      if (version[i] != EEPROM.read(i)) {
        writeDefaults = true;
        i = sizeof(version); // get out
      }
    }*/
    if (writeDefaults) {
      applyDefaultsToSettings();
      makeInitialized();
    }
  }

  void makeInitialized(){
    Serial.println(F("Initializing..."));
    for (byte i=0;i<sizeof(Initialized)-1;i++){
      EEPROM.write(i, Initialized[i]);
    }
    /*for (byte i=0;i<sizeof(version)-1;i++){
      EEPROM.write(i, version[i]);
    }*/
  }

  void applyDefaultsToSettings(){
    Serial.println(F("Applying defaults to settings..."));

    SETTINGS_APRS_BEACON_ENABLED = true;
    
    SETTINGS_APRS_BEACON_DISTANCE = 0.5000;

    SETTINGS_APRS_BEACON_IDLE_TIME = 30000;

    const char* strTemp1 = "NOCALL>APRS,WIDE1-1,WIDE2-1:!0000.00N/00000.00W>HamMessenger Ready";
    for (int i=0; i<=strlen(strTemp1);i++) {
      SETTINGS_APRS_RAW_PACKET[i] = strTemp1[i];
    }

    const char* strTemp2 = "https://github.com/dalethomas81/HamMessenger";
    for (int i=0; i<=strlen(strTemp2);i++) {
      SETTINGS_APRS_COMMENT[i] = strTemp2[i];
    }

    const char* strTemp3 = "Hi!";
    for (int i=0; i<=strlen(strTemp3);i++) {
      SETTINGS_APRS_MESSAGE[i] = strTemp3[i];
    }

    //
    const char* strTemp4 = "NOCALL";
    for (int i=0; i<=strlen(strTemp4);i++) {
      SETTINGS_APRS_RECIPIENT_CALL[i] = strTemp4[i];
    }
    SETTINGS_APRS_RECIPIENT_SSID[0] = '0';
    SETTINGS_APRS_RECIPIENT_SSID[1] = '\0';

    //
    const char* strTemp5 = "NOCALL";
    for (int i=0; i<=strlen(strTemp5);i++) {
      SETTINGS_APRS_CALLSIGN[i] = strTemp5[i];
    }
    SETTINGS_APRS_CALLSIGN_SSID[0] = '0';
    SETTINGS_APRS_CALLSIGN_SSID[1] = '\0';

    //
    const char* strTemp6 = "APRS";
    for (int i=0; i<=strlen(strTemp6);i++) {
      SETTINGS_APRS_DESTINATION_CALL[i] = strTemp6[i];
    }
    SETTINGS_APRS_DESTINATION_SSID[0]  = '1';
    SETTINGS_APRS_DESTINATION_SSID[1] = '\0';

    //
    const char* strTemp7 = "WIDE1";
    for (int i=0; i<=strlen(strTemp7);i++) {
      SETTINGS_APRS_PATH1_CALL[i] = strTemp7[i];
    }
    SETTINGS_APRS_PATH1_SSID[0] = '1';
    SETTINGS_APRS_PATH1_SSID[1] = '\0';

    //
    const char* strTemp8 = "WIDE2";
    for (int i=0; i<=strlen(strTemp8)-1;i++) {
      SETTINGS_APRS_PATH2_CALL[i] = strTemp8[i];
    }
    SETTINGS_APRS_PATH2_SSID[0] = '2';
    SETTINGS_APRS_PATH2_SSID[1] = '\0';

    //
    SETTINGS_APRS_SYMBOL[0] = 'n';
    SETTINGS_APRS_SYMBOL[1] = '\0';
    SETTINGS_APRS_SYMBOL_TABLE[0] = 's';
    SETTINGS_APRS_SYMBOL_TABLE[1] = '\0';

    SETTINGS_APRS_AUTOMATIC_ACK = true;

    SETTINGS_APRS_PREAMBLE = 350;

    SETTINGS_APRS_TAIL = 80;

    SETTINGS_APRS_RETRY_COUNT = 2;

    SETTINGS_APRS_RETRY_INTERVAL = 10000;
    
    SETTINGS_GPS_POSITION_TOLERANCE = 0.01;  // unit is in degrees

    // London  LAT:51.508131     LNG:-0.128002
    SETTINGS_GPS_DESTINATION_LATITUDE = 51.508131;

    SETTINGS_GPS_DESTINATION_LONGITUDE = -0.128002;
    
    SETTINGS_DISPLAY_TIMEOUT = 120000;

    SETTINGS_DISPLAY_BRIGHTNESS = 100;

    SETTINGS_DISPLAY_SHOW_POSITION = true;

    SETTINGS_DISPLAY_SCROLL_MESSAGES = true;

    SETTINGS_DISPLAY_SCROLL_SPEED = 4;

    SETTINGS_DISPLAY_INVERT= false;

    writeSettingsToEeprom();
  }

  void writeSettingsToEeprom(){
    Serial.println(F("Writing settings..."));
    
    /*Settings Settings_Default;
    int address = EEPROM_SETTINGS_START_ADDR;
    EEPROM.put(address, Settings_Default);
    address = address + sizeof(Settings_Default);
    Serial.print(F("Settings size =")); Serial.println(sizeof(Settings_Default));*/

    int address = EEPROM_SETTINGS_START_ADDR;
    for (int i=0;i<ARRAY_SIZE(Settings_TypeBool);i++){
      //Serial.print(F("bool:"));Serial.print(address);Serial.print(":");Serial.println(Settings_TypeBool[i]);
      EEPROM.put(address, Settings_TypeBool[i]);
      address = address + sizeof(Settings_TypeBool[i]);
    }
    for (int i=0;i<ARRAY_SIZE(Settings_TypeInt);i++){
      //Serial.print(F("int:"));Serial.print(address);Serial.print(":");Serial.println(Settings_TypeInt[i]);
      EEPROM.put(address, Settings_TypeInt[i]);
      address = address + sizeof(Settings_TypeInt[i]);
    }
    for (int i=0;i<ARRAY_SIZE(Settings_TypeUInt);i++){
      //Serial.print(F("uint:"));Serial.print(address);Serial.print(":");Serial.println(Settings_TypeUInt[i]);
      EEPROM.put(address, Settings_TypeUInt[i]);
      address = address + sizeof(Settings_TypeUInt[i]);
    }
    for (int i=0;i<ARRAY_SIZE(Settings_TypeLong);i++){
      //Serial.print(F("long:"));Serial.print(address);Serial.print(":");Serial.println(Settings_TypeLong[i]);
      EEPROM.put(address, Settings_TypeLong[i]);
      address = address + sizeof(Settings_TypeLong[i]);
    }
    for (int i=0;i<ARRAY_SIZE(Settings_TypeULong);i++){
      //Serial.print(F("ulong:"));Serial.print(address);Serial.print(":");Serial.println(Settings_TypeULong[i]);
      EEPROM.put(address, Settings_TypeULong[i]);
      address = address + sizeof(Settings_TypeULong[i]);
    }
    for (int i=0;i<ARRAY_SIZE(Settings_TypeFloat);i++){
      //Serial.print(F("float:"));Serial.print(address);Serial.print(":");Serial.println(Settings_TypeFloat[i]);
      EEPROM.put(address, Settings_TypeFloat[i]);
      address = address + sizeof(Settings_TypeFloat[i]);
    }
    for (int i=0;i<ARRAY_SIZE(Settings_TypeString2);i++){
      //Serial.print(F("Settings_TypeString2:"));Serial.print(address);Serial.print(":");
      for (int j=0;j<sizeof(Settings_TypeString2[i]);j++){
        EEPROM.put(address, Settings_TypeString2[i][j]);
        address = address + sizeof(Settings_TypeString2[i][j]);
      }
      //Serial.println(Settings_TypeString2[i]);
    }
    for (int i=0;i<ARRAY_SIZE(Settings_TypeString3);i++){
      //Serial.print(F("Settings_TypeString3:"));Serial.print(address);Serial.print(":");
      for (int j=0;j<sizeof(Settings_TypeString3[i]);j++){
        EEPROM.put(address, Settings_TypeString3[i][j]);
        address = address + sizeof(Settings_TypeString3[i][j]);
      }
      //Serial.println(Settings_TypeString3[i]);
    }
    for (int i=0;i<ARRAY_SIZE(Settings_TypeString7);i++){
      //Serial.print(F("Settings_TypeString7:"));Serial.print(address);Serial.print(":");
      for (int j=0;j<sizeof(Settings_TypeString7[i]);j++){
        EEPROM.put(address, Settings_TypeString7[i][j]);
        address = address + sizeof(Settings_TypeString7[i][j]);
      }
      //Serial.println(Settings_TypeString7[i]);
    }
    for (int i=0;i<ARRAY_SIZE(Settings_TypeString100);i++){
      //Serial.print(F("Settings_TypeString100:"));Serial.print(address);Serial.print(":");
      for (int j=0;j<sizeof(Settings_TypeString100[i]);j++){
        EEPROM.put(address, Settings_TypeString100[i][j]);
        address = address + sizeof(Settings_TypeString100[i][j]);
      }
      //Serial.println(Settings_TypeString100[i]);
    }
  }
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
void loop(){
  handleKeyboard();
  handleSettings();
  handleDisplays();
  handleSerial();
  handleSendMessage();
  handleModemCommands();
  handleAprsBeacon();
  handleVoltage();
  handleStats();

  // printing all contents from SD card is non-blocking
  if (readingSD) {
    printRawDataFromSd();
  }
}

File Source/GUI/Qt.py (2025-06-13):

import sys
import serial
import serial.tools.list_ports
from PySide6.QtWidgets import (
    QApplication, QMainWindow, QWidget, QVBoxLayout, QHBoxLayout, QTabWidget,
    QLabel, QComboBox, QPushButton, QPlainTextEdit, QLineEdit, QFileDialog,
    QMessageBox, QCheckBox, QBoxLayout
)
from PySide6.QtCore import Qt, QTimer, QThread, Signal, QUrl, Signal
from PySide6.QtWebEngineWidgets import QWebEngineView
from PySide6.QtGui import QTextCharFormat, QTextCursor, QColor, QFont
from datetime import datetime
import re
import base64
from queue import Queue
import platform
from aprspy import APRS

IS_DARK_MODE = True
IS_MAC = platform.system() == "Darwin"
IS_WINDOWS = platform.system() == "Windows"

symbol_map = {
    # Primary Table ('/')
    "/!": "Emergency",
    "/\"": "Reserved (not used)",
    "/#": "Digipeater",
    "/$": "Phone",
    "/%": "DX Cluster",
    "/&": "HF Gateway",
    "/'": "Small Aircraft",
    "/(": "Mobile Satellite Station",
    "/)": "Wheelchair",
    "/*": "Snowmobile",
    "/+": "Red Cross",
    "/,": "Boy Scout",
    "/-": "House (QTH)",
    "/.": "X — Overlay position",
    "/0": "Circle (Node)",
    "/1": "ARC",
    "/2": "Bicycle",
    "/3": "Church",
    "/4": "Campground",
    "/5": "QTH with phone",
    "/6": "iGate",
    "/7": "Aircraft (large)",
    "/8": "Boat",
    "/9": "Motorcycle",
    "/:": "Fire Dept",
    "/;": "Police Station",
    "/<": "Truck",
    "/=": "RV",
    "/>": "Car",
    "/?": "Info Kiosk",
    "@/": "JOTA (Scouts)",
    "/A": "Ambulance",
    "/B": "BBS",
    "/C": "Computer",
    "/D": "Delivery Truck",
    "/E": "Eyeball (Meeting)",
    "/F": "Satellite",
    "/G": "GPS Receiver",
    "/H": "Hospital",
    "/I": "TNC",
    "/J": "Jeep",
    "/K": "School",
    "/L": "Laptop",
    "/M": "Mic/Echolink",
    "/N": "NTS Traffic",
    "/O": "Balloon",
    "/P": "Parking",
    "/Q": "ATV",
    "/R": "Repeater",
    "/S": "Ship",
    "/T": "Truck Stop",
    "/U": "Bus",
    "/V": "Van",
    "/W": "Water Station",
    "/X": "Helicopter",
    "/Y": "Yacht",
    "/Z": "Winlink",
    
    # Alternate Table ('\\')
    "\\!": "Police Car",
    "\\\"": "Reserved",
    "\\#": "Smoke Detector",
    "\\$": "Cash Register",
    "\\%": "Power Plant",
    "\\&": "Topo Map",
    "\\'": "Crash Site",
    "\\(": "Cloudy",
    "\\)": "Rain",
    "\\*": "Snow",
    "\\+": "Church (alt)",
    "\\,": "Girl Scout",
    "\\-": "QSL Card",
    "\\.": "Ambulance (alt)",
    "\\0": "Circle+overlay",
    "\\1": "Power Outage",
    "\\2": "Tornado",
    "\\3": "Flood",
    "\\4": "Solar Power",
    "\\5": "Tsunami",
    "\\6": "Civil Defense",
    "\\7": "Hazard",
    "\\8": "Radiation",
    "\\9": "Biohazard",
    "\\:": "Fog",
    "\\;": "Snowstorm",
    "\\<": "Hurricane",
    "\\=": "Volcano",
    "\\>": "Lightning",
    "\\?": "Dust",
    "\\A": "Box/Package",
    "\\B": "Blowing Snow",
    "\\C": "Coastal Flood",
    "\\D": "Drizzle",
    "\\E": "Freezing Rain",
    "\\F": "Funnel Cloud",
    "\\G": "Gale",
    "\\H": "Hail",
    "\\I": "Icy Roads",
    "\\J": "Jackknife",
    "\\K": "Blizzard",
    "\\L": "Low Visibility",
    "\\M": "Moon",
    "\\N": "News Station",
    "\\O": "Balloon (alt)",
    "\\P": "Pick-up Truck",
    "\\Q": "Quake",
    "\\R": "Rocket",
    "\\S": "Sleet",
    "\\T": "Thunderstorm",
    "\\U": "Sun",
    "\\V": "VHF Station",
    "\\W": "Flooding",
    "\\X": "X-ray",
    "\\Y": "Yagi Antenna",
    "\\Z": "Zombie (!)"
}
emoji_map = {
    # Primary Symbol Table ('/')
    "/!": "🚨",  # Emergency
    "/#": "📶",  # Digipeater
    "/$": "📞",  # Phone
    "/%": "🗼",  # DX Cluster
    "/&": "🌐",  # HF Gateway
    "/'": "🛩️",  # Small aircraft
    "/(": "🛰️",  # Mobile satellite
    "/)": "♿",  # Wheelchair
    "/*": "🏂",  # Snowmobile
    "/+": "➕",  # Red Cross
    "/,": "🏕️",  # Boy Scout
    "/-": "🏠",  # Home / QTH
    "/.": "❌",  # Overlay position
    "/0": "⭕",  # Circle (Node)
    "/1": "🏢",  # Icon (generic)
    "/2": "🚴",  # Bicycle
    "/3": "⛪",  # Church
    "/4": "⛺",  # Campground
    "/5": "📱",  # QTH with phone
    "/6": "📡",  # iGate
    "/7": "✈️",  # Large aircraft
    "/8": "⛵",  # Boat
    "/9": "🏍️",  # Motorcycle
    "/:": "🚒",  # Fire Dept
    "/;": "🚓",  # Police Station
    "/<": "🚚",  # Truck
    "/=": "🚐",  # RV
    "/>": "🚗",  # Car
    "/?": "ℹ️",  # Info Kiosk
    "/A": "🚑",  # Ambulance
    "/B": "📦",  # BBS
    "/C": "🖥️",  # Computer
    "/D": "📦",  # Delivery Truck
    "/E": "👀",  # Eyeball / Event
    "/F": "🛰️",  # Satellite
    "/G": "📍",  # GPS Receiver
    "/H": "🏥",  # Hospital
    "/I": "📡",  # TNC
    "/J": "🚙",  # Jeep
    "/K": "🏫",  # School
    "/L": "💻",  # Laptop
    "/M": "🎙️",  # Mic / EchoLink
    "/N": "📨",  # NTS Traffic
    "/O": "🎈",  # Balloon
    "/P": "🅿️",  # Parking
    "/Q": "📺",  # ATV (TV)
    "/R": "📡",  # Repeater
    "/S": "🚢",  # Ship
    "/T": "⛽",  # Truck Stop
    "/U": "🚌",  # Bus
    "/V": "🚐",  # Van
    "/W": "🚰",  # Water Station
    "/X": "🚁",  # Helicopter
    "/Y": "🛥️",  # Yacht
    "/Z": "📬",  # Winlink

    # 
    "/[": "🚶",  # Walking person
    "/]": "🏃",  # Running person
    "/{": "🎒",  # Hiking
    "/}": "🎿",  # Skier
    "/|": "🗼",  # Tower
    "/\\": "💻",  # PC station
    "/^": "📻",  # Ham shack
    "/_": "🛶",  # Watercraft
    "/`": "🌦️",  # Alt weather
    "/~": "🏠",  # House alt
    "/b": "🚴",  # Bicycle

    # Alternate Symbol Table ('\\')
    "\\!": "🚓",  # Police car
    "\\#": "🔥",  # Smoke detector
    "\\$": "💵",  # Cash register
    "\\%": "🏭",  # Power Plant
    "\\&": "🗺️",  # Topo Map
    "\\'": "💥",  # Crash Site
    "\\(": "☁️",  # Cloudy
    "\\)": "🌧️",  # Rain
    "\\*": "❄️",  # Snow
    "\\+": "✝️",  # Church (alt)
    "\\,": "👧",  # Girl Scout
    "\\-": "📮",  # QSL Card
    "\\0": "⭘",  # Overlay circle
    "\\1": "💡",  # Power outage
    "\\2": "🌪️",  # Tornado
    "\\3": "🌊",  # Flood
    "\\4": "🔋",  # Solar Power
    "\\5": "🌊",  # Tsunami
    "\\6": "🏛️",  # Civil Defense
    "\\7": "☢️",  # Hazard
    "\\8": "☢️",  # Radiation
    "\\9": "☣️",  # Biohazard
    "\\:": "🌫️",  # Fog
    "\\;": "🌨️",  # Snowstorm
    "\\<": "🌀",  # Hurricane
    "\\=": "🌋",  # Volcano
    "\\>": "🌩️",  # Lightning
    "\\?": "💨",  # Dust
    "\\A": "📦",  # Box/Package
    "\\B": "🌬️",  # Blowing snow
    "\\C": "🌊",  # Coastal Flood
    "\\D": "🌦️",  # Drizzle
    "\\E": "🌧️",  # Freezing Rain
    "\\F": "🌪️",  # Funnel Cloud
    "\\G": "🌬️",  # Gale
    "\\H": "🌨️",  # Hail
    "\\I": "🧊",  # Icy Roads
    "\\J": "🚛",  # Jackknife
    "\\K": "🌨️",  # Blizzard
    "\\L": "🌁",  # Low Visibility
    "\\M": "🌕",  # Moon
    "\\N": "📰",  # News Station
    "\\O": "🎈",  # Balloon (alt)
    "\\P": "🛻",  # Pickup Truck
    "\\Q": "🌎",  # Earthquake
    "\\R": "🚀",  # Rocket
    "\\S": "🌨️",  # Sleet
    "\\T": "⛈️",  # Thunderstorm
    "\\U": "☀️",  # Sun
    "\\V": "📡",  # VHF Station
    "\\W": "🌊",  # Flooding
    "\\X": "☢️",  # X-ray (symbol)
    "\\Y": "📡",  # Yagi antenna
    "\\Z": "🧟",  # Zombie
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

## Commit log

2021-06-27 update readme. add print and save to serial
2021-06-27 add modem command to printout
2021-06-27 esc button cancels edit. enter button confirms.
2021-06-27 remove reference to buttons
2021-06-27 fix issue where float doesnt copy to temp var
    [HamMessenger.ino]
2021-06-28 fix issue where float val does not negate
    [HamMessenger.ino]
2021-06-28 refactor printing value stored in mem to function
2021-06-29 Begin work on PCB. Add schematic (WIP)
    [Shield.brd, Shield.sch]
2021-06-30 Continue work on PCB. Update schematic.
    [Shield.brd, Shield.sch]
2021-07-01 Fix settings arent accepted via command prompt
    [HamMessenger.ino]
2021-07-01 Fix issue with dynamic number of items in settings
    [HamMessenger.ino]
2021-07-03 fix issue with gps tolerance
    [HamMessenger.ino]
2021-07-03 add dxf for arduino mega 2560
    [dimensioniMega.dxf]
2021-07-04 Net re-routing
    [Shield.brd, Shield.sch]
2021-07-04 PCB Updates
    [Shield.brd, Shield.sch]
2021-07-04 Add ground plane
    [Shield.brd]
2021-07-04 add SD card. rerouting.
    [Shield.brd, Shield.sch]
2021-07-05 add grove connector
2021-07-05 Add text to silkscreen
    [Shield.brd]
2021-07-05 Change pins grove keyboard connector.
    [Shield.brd, Shield.sch]
2021-07-05 Last minute tweeks before sending to fab.
    [Shield.brd, Shield.sch]
2021-07-05 BOM updates
    [BOM.csv]
2021-07-05 Add cardkb
    [Mouser.xls]
2021-07-05 updated schematic and BOM
    [Shield.brd]
2021-07-11 read and write raw and messages. print to terminal
2021-07-11 Add information on parts and libraries.
    [Mouser.xls, dimensioniMega.dxf]
2021-07-15 fix issue where SD file buffer overflows
    [HamMessenger.ino]
2021-07-18 Rearrange folders
    [BOM.csv, Shield.brd, Shield.sch]
2021-07-19 Update Mouser BOM for 1 HamMessenger
2021-07-19 make BOMs more clear. Add BOM info.
2021-07-19 Add clarity to readme. add shared board link
2021-07-21 Board updates
2021-07-22 Board fixes / improvements
    [Shield.brd, Shield.sch]
2021-07-23 board analysis
2021-07-24 final touch before fab
    [Shield.brd]
2021-07-24 gerber files and jlcpcb cam
2021-07-28 convert position tolerance to degrees
    [HamMessenger.ino]
2021-09-05 add unibody frame files
    [HamMessenger.f3d, UniBody.stl]
2021-09-05 update readme on unibody frame
    [HamMessenger.f3d, UniBody.stl]
2021-09-08 update arduino extension settings vscode
2023-01-29 remove typo. update arduino config.
2025-05-04 print raw messages
2025-05-05 log filtering
2025-05-07 mic-e decode, message threading
2025-05-07 wash gitignore
    [dimensioniMega.dxf]
2025-05-08 Raw SD card print non-blocking
2025-05-11 move CAD into source folder
    [BOM.csv, HamMessenger.f3d, Shield.brd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]
2025-05-11 messages bug
    [BOM.csv, Shield-Electronic-Design.f3z, Shield.brd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]
2025-05-11 front cover
    [Front Cover.stl]
2025-05-11 add enclosure front cover. clean old files.
    [Enclosure.f3d, HamMessenger.f3d]
2025-05-12 back cover. front cover gps.
    [Back Cover.stl, Enclosure.f3d, Front Cover.stl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]
2025-05-14 enclosure. gps logic.
    [Back Cover.stl, Enclosure.f3d, Front Cover.stl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]
2025-05-17 update PCB with RC filter for RF mitigation
    [Back Cover.stl, Enclosure.f3d, Front Cover.stl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]
2025-05-17 update BOM
2025-05-26 Update CAD view
2025-05-27 - fix issue where raw modem output is null terminated too short. - increased the SSID size from 1 character to 2 characters. - add ability to scroll text in and out of the window using left and right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
    [HamMessenger.ino]
2025-06-03 add info to pin popup
2025-06-07 resolve issue with terminal SSID command
    [HamMessenger.ino, Qt.py]
2025-06-08 generate shield v1.2 schematics
2025-06-08 tighten up front cover. remove material new cable
    [Front Cover.stl]
2025-06-09 [Terminal] resolve issues with string names and size
    [HamMessenger.ino, Qt.py]
2025-06-12 resolve issue with default settings
    [HamMessenger.ino]

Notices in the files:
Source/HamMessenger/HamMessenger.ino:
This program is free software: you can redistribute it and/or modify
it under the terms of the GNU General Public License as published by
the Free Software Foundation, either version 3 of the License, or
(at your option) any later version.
